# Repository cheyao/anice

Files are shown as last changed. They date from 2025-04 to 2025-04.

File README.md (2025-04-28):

# Icedev & Anice

*"FPGAs work like this. You don't tell them what to do, you tell them what to BE."*

An FPGA is a chip that can be configured on the hardware level. You can basically make your own CPU and GPU on it.

This project is composed of a PCB duo, that will be later joined together:

The first PCB called "icedev" is a ICE40 FPGA development board:
- 16MHz clock
- 64KiB eeprom
- 128MiB flash
- 1.2MiB of RAM
- dual usb-c
- multi voltage
It's equivalent is like the raspberry pico (orph pico)

The second, called "anice":
- 256MiB of ram
- 128MiB of flash
- HDMI port
- triple USB C with JTAG converter
- SDCard Reader
- dual 25MHz clock and 200MHz built-in clock
- multiple indicator lights
- only 4 layer PCB

View online demo on [kicanvas](https://kicanvas.org/?github=https%3A%2F%2Fgithub.com%2Fcheyao%2Fanice%2Ftree%2Fmain%2Fsrc%2F)!

The repo stucture is a bit messy because I wanted the two designs to appear together on kicanvas.

## Anice:



## Icedev:



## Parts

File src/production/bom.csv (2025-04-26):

Designator | Footprint | Quantity | Value | LCSC Part #
C10, C21, C27, C29 | 0603 | 4 | 100pF | C14858
C11, C12, C2, C25, C28, C3, C30, C32, C4, C8, C9 | 0603 | 11 | 10uF | C19702
C13, C14, C15, C16, C17, C18, C19, C20 | 0402 | 8 | 22nF | C1532
C22 | 0603 | 1 | 22uF | C59461
C23, C26, C31, C33, C34, C35, C36, C37, C38, C39, C41, C42, C43 | 0402 | 13 | 100nF | C1525
C40 | 0402 | 1 | 5pF | C541339
D1 | 0603 | 1 | RED | C2286
D2 | 0603 | 1 | GREEN | C2994781
D3 | 0603 | 1 | YELLOW | C72038
J2 | SDCard molex | 1 | Micro_SD_Card_Det1 | C20613194
J3, J4, J5 | USB_C_Receptacle_GCT_USB4105-xx-A_16P_TopMnt_Horizontal | 3 | USB_C_Receptacle_USB2.0_14P | C2765186
J7 | XKB Connection A71-05H4-111N1 | 1 | HDMI_C_1.3 | C2682170
L1, L2, L3 | 1008 | 3 | 2.2uH | C285758
R1, R2, R3, R4, R6, R7 | 0603 | 6 | 5.1k | C23186
R10, R8 | 0603 | 2 | 470 | C23179
R11 | 0603 | 1 | 100k | C25803
R12, R13, R16, R17, R23, R24, RB2 | 0603 | 7 | 4.7k | C23162
R14, R15, RB3 | 0603 | 3 | 3.3k | C22978
R18 | 0603 | 1 | 1k | C21190
R19, R20, R21, R22, R9 | 0603 | 5 | 10k | C25804
R25, R26, R5 | 0603 | 3 | 549 | C23204
R38 | 0603 | 1 | 0.47 | C3013349
RA1, RA2, RA3 | 0603 | 3 | 15k | C22809
RB1 | 0603 | 1 | 18k | C25810
U1 | BGA-256_14.0x14.0mm_Layout16x16_P0.8mm_Ball0.45mm_Pad0.32mm_NSMD | 1 | ECP5U_12_CABGA256 | C1521614
U10 | TSOP-II-54_22.2x10.16mm_P0.8mm | 1 | W9825G6KH-6 | C62246
U11 | SOIC-8_5.3x5.3mm_P1.27mm | 1 | W25Q128JVS | C97521
U12, U13, U14 | SOT-563 | 3 | TLV62569DRL | C163217
U5, U6, U8 | Texas_DRT-3 | 3 | TPD2EUSB30 | C2844720
U7 | QFN-20-1EP_4x4mm_P0.5mm_EP2.5x2.5mm | 1 | FT231XQ | C132159
U9 | VSSOP-8_2.3x2mm_P0.5mm | 1 | PCA9306DC1 | C129510
Y1 | Crystal_SMD_3225-4Pin_3.2x2.5mm | 1 | ECS-2520MV-xxx-xx | C5189451

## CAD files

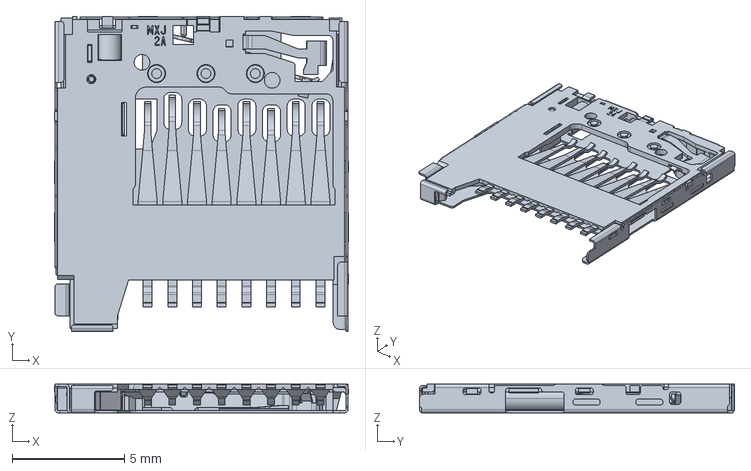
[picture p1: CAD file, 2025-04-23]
src/5033981892.stp
13.1 x 14.0 x 1.28 mm

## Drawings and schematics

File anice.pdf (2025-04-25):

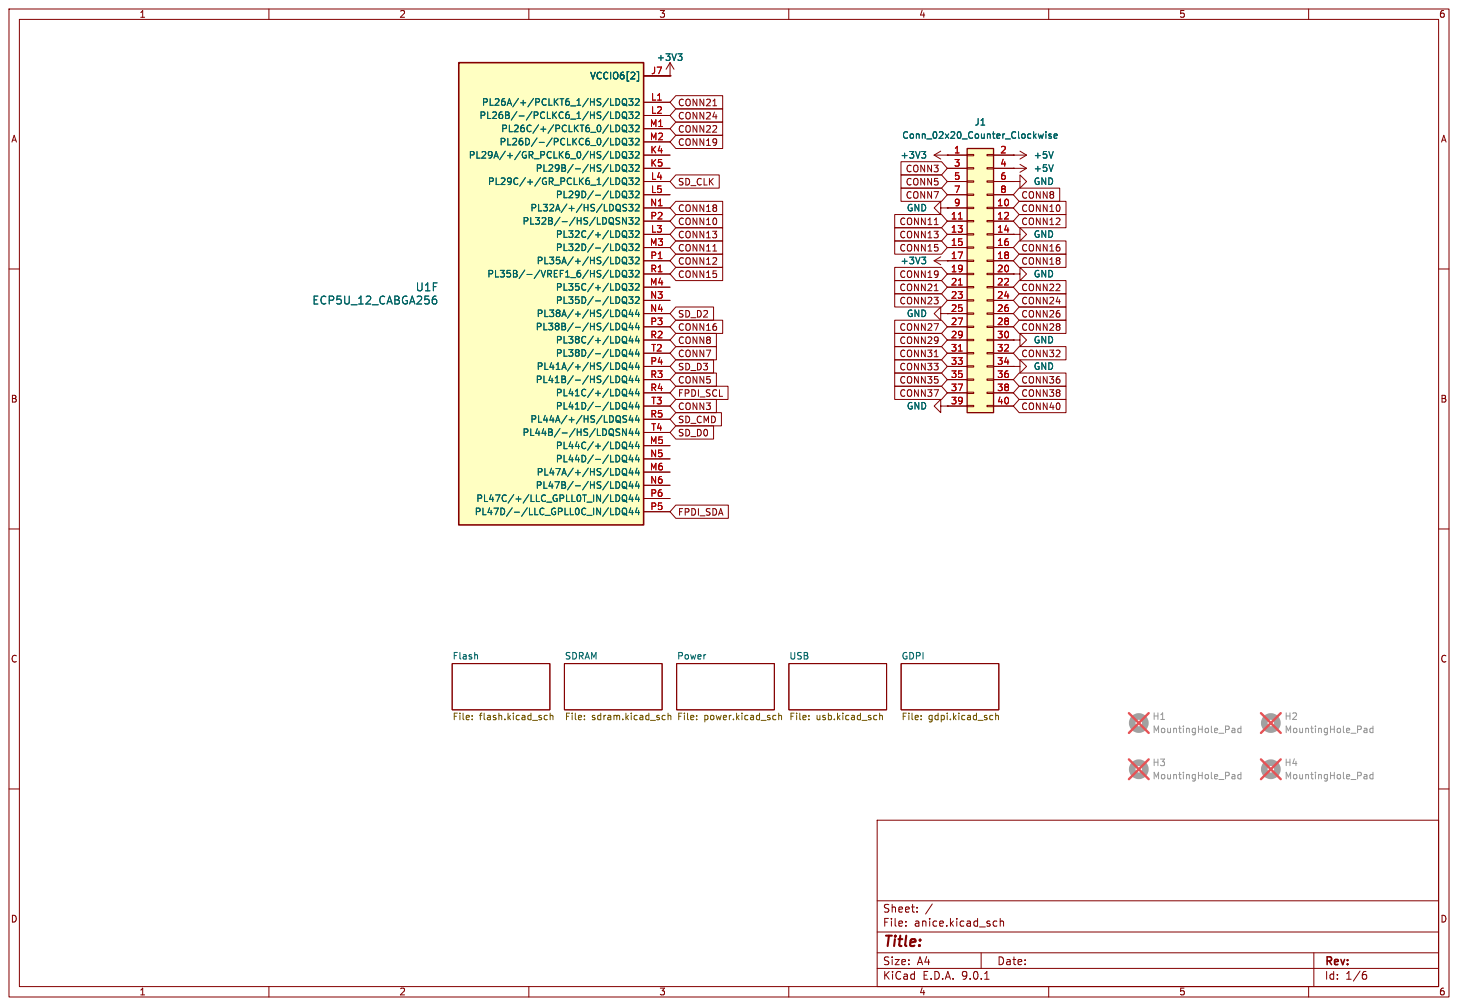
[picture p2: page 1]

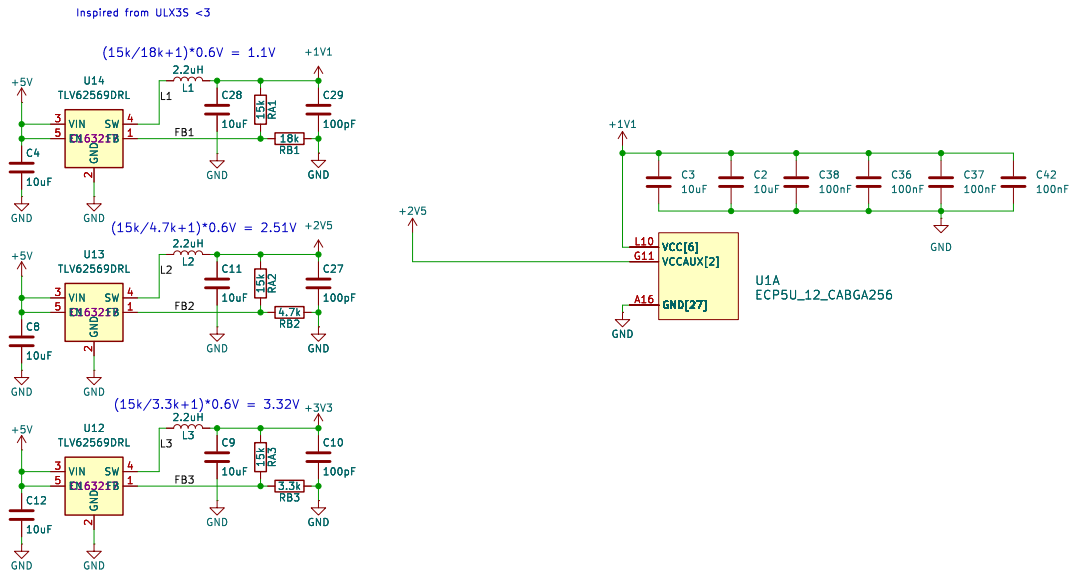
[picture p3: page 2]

2 SW 4 FB 1 U13 TLV62569DRL C163217 +5V
Id: 2/6 Title: File: power.kicad_sch Sheet: /Power/ +3V3 +5V

2 SW 4 FB 1 U13 TLV62569DRL C163217 VIN 3 EN 5 GND

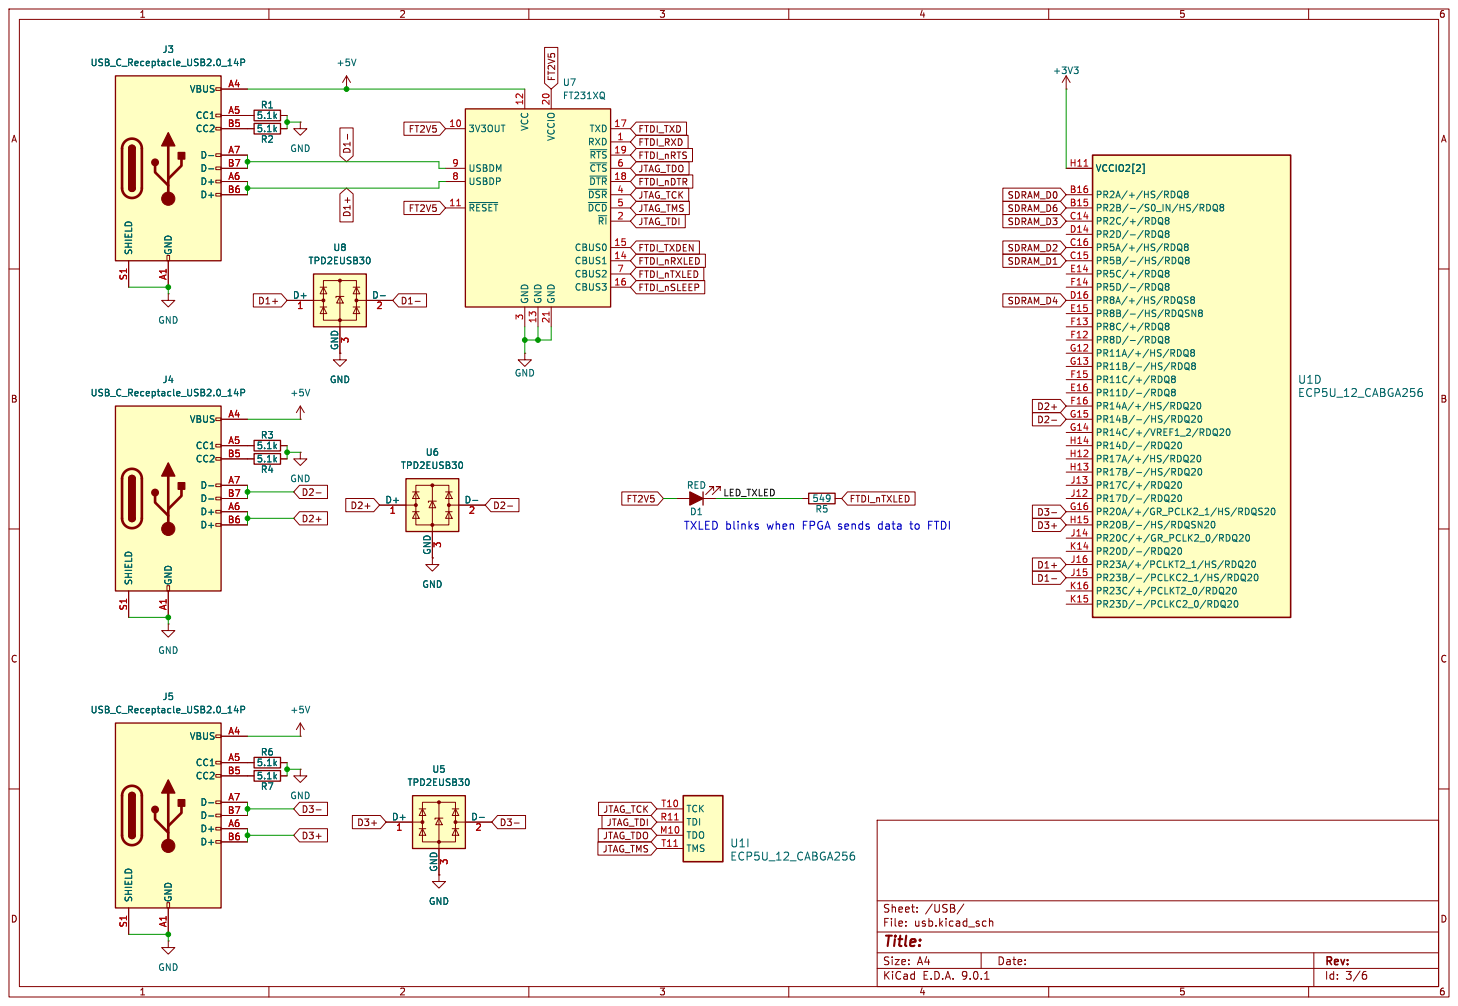
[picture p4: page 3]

3 GND 13 VCCIO 20 GND 21 TXD 17 RXD 1 ~{RTS}19 ~{CTS}6 ~{DTR}18 ~{DSR}4 ~{DCD}5 ~{RI}2 CBUS0 15 CBUS1 14 CBUS2 7 CBUS3 16 U7 FT231XQ
JTAG_TDI FTDI_RXD

Id: 3/6 Title: File: usb.kicad_sch Sheet: /USB/

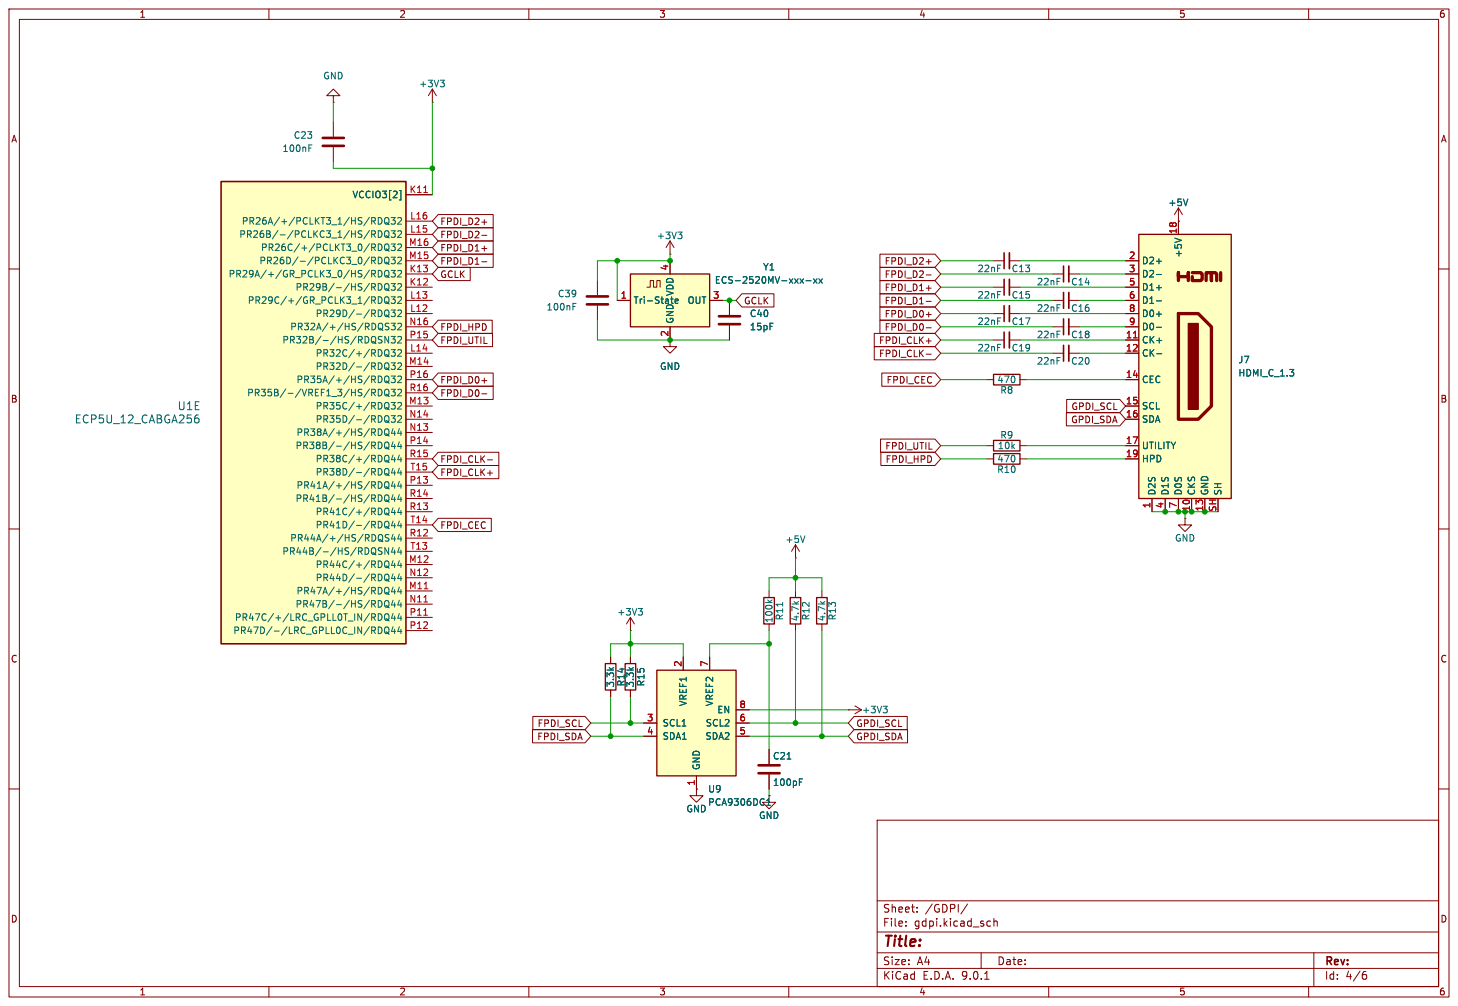
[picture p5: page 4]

2 OUT 3 Y1 ECS-2520MV-xxx-xx +3V3 3.3k R14 3.3k R15 SCL1 3 SDA1 4 VREF1

7 EN 8 SCL2 6 SDA2 5 3.3k R14 3.3k R15 Y1 ECS-2520MV-xxx-xx Tri-State 1 VDD

7 CKS 10 GND 13 SH SH

Id: 4/6 Title: File: gdpi.kicad_sch Sheet: /GDPI/

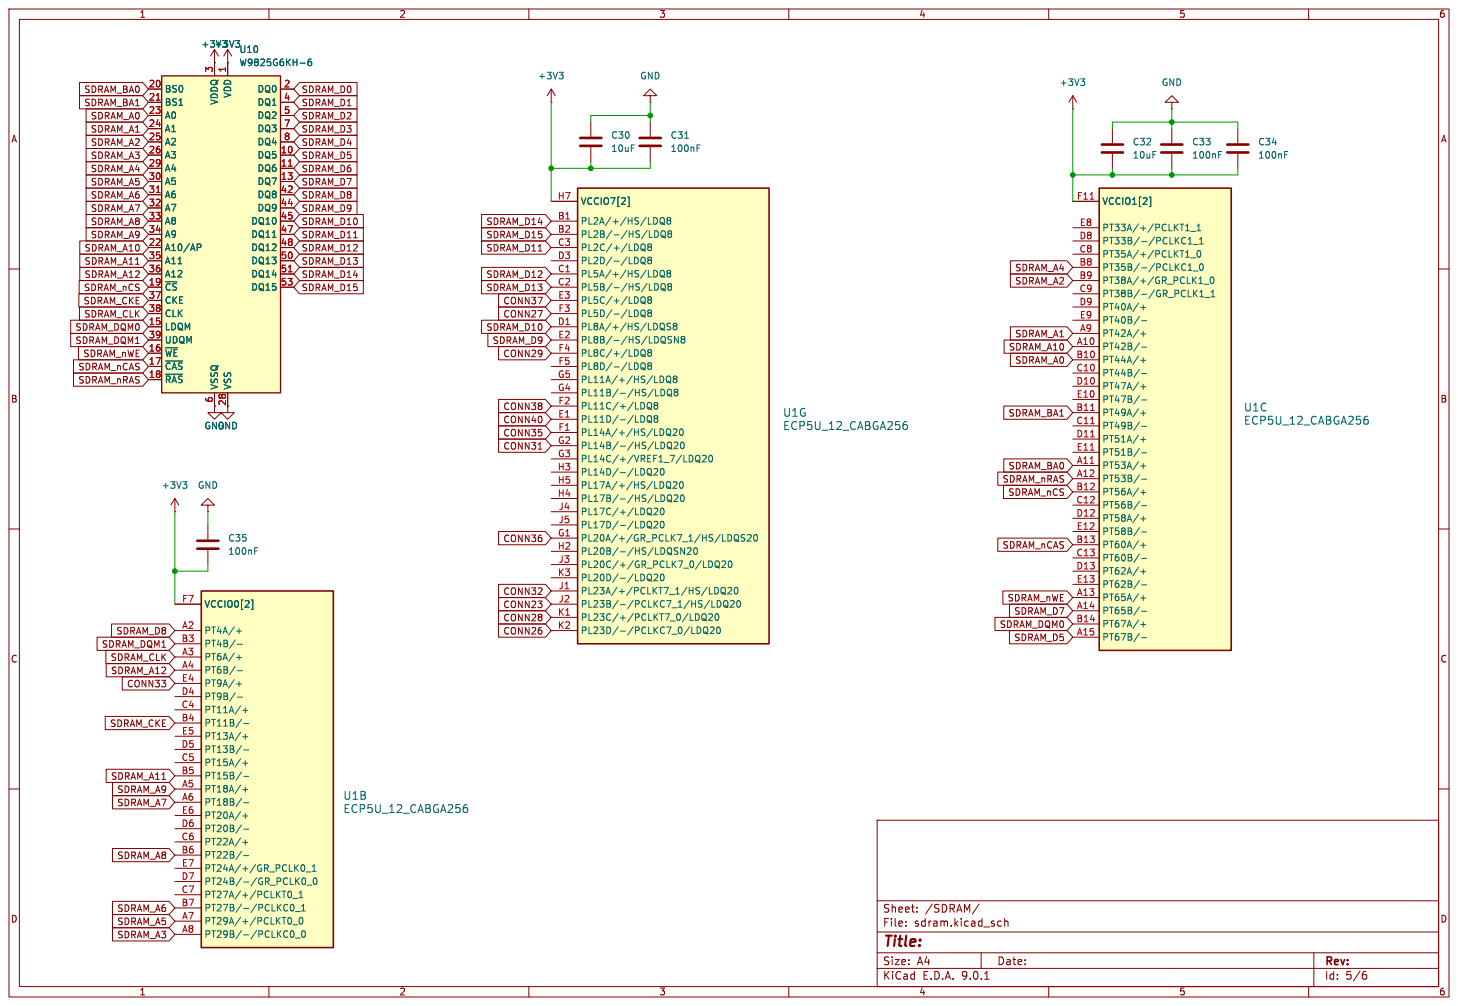
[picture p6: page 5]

U10 W9825G6KH-6 BS0 20 BS1 21 A0 23 A1 24 A2 25 A3 26 A4 29 A5 30 A6 31 A7 32 A8 33 A9 34 A10/AP 22 A11 35 A12 36 ~{CS} 19 CKE 37 CLK 38

1 VSS 28 DQ0 2 DQ1 4 DQ2 5 DQ3 7 DQ4 8 DQ5 10 DQ6 11 DQ7 13 DQ8 42 DQ9 44 DQ10 45 DQ11 47 DQ12 48 DQ13 50 DQ14 51 DQ15 53 U10 W9825G6KH-6 GND GND GND GND

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

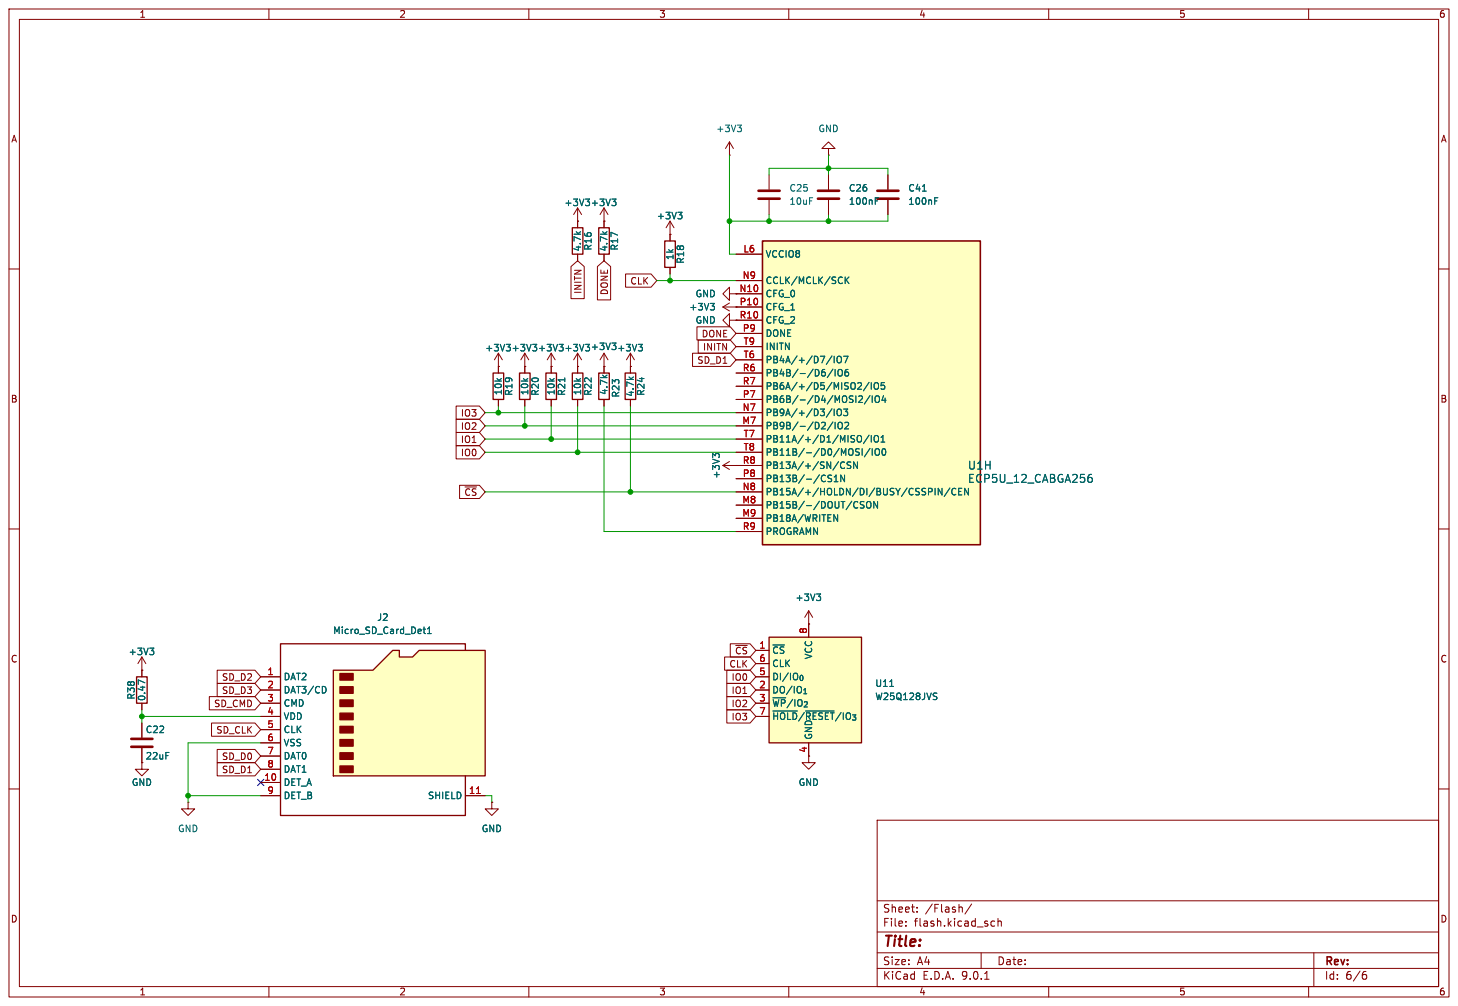
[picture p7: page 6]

Id: 6/6 Title: File: flash.kicad_sch Sheet: /Flash/

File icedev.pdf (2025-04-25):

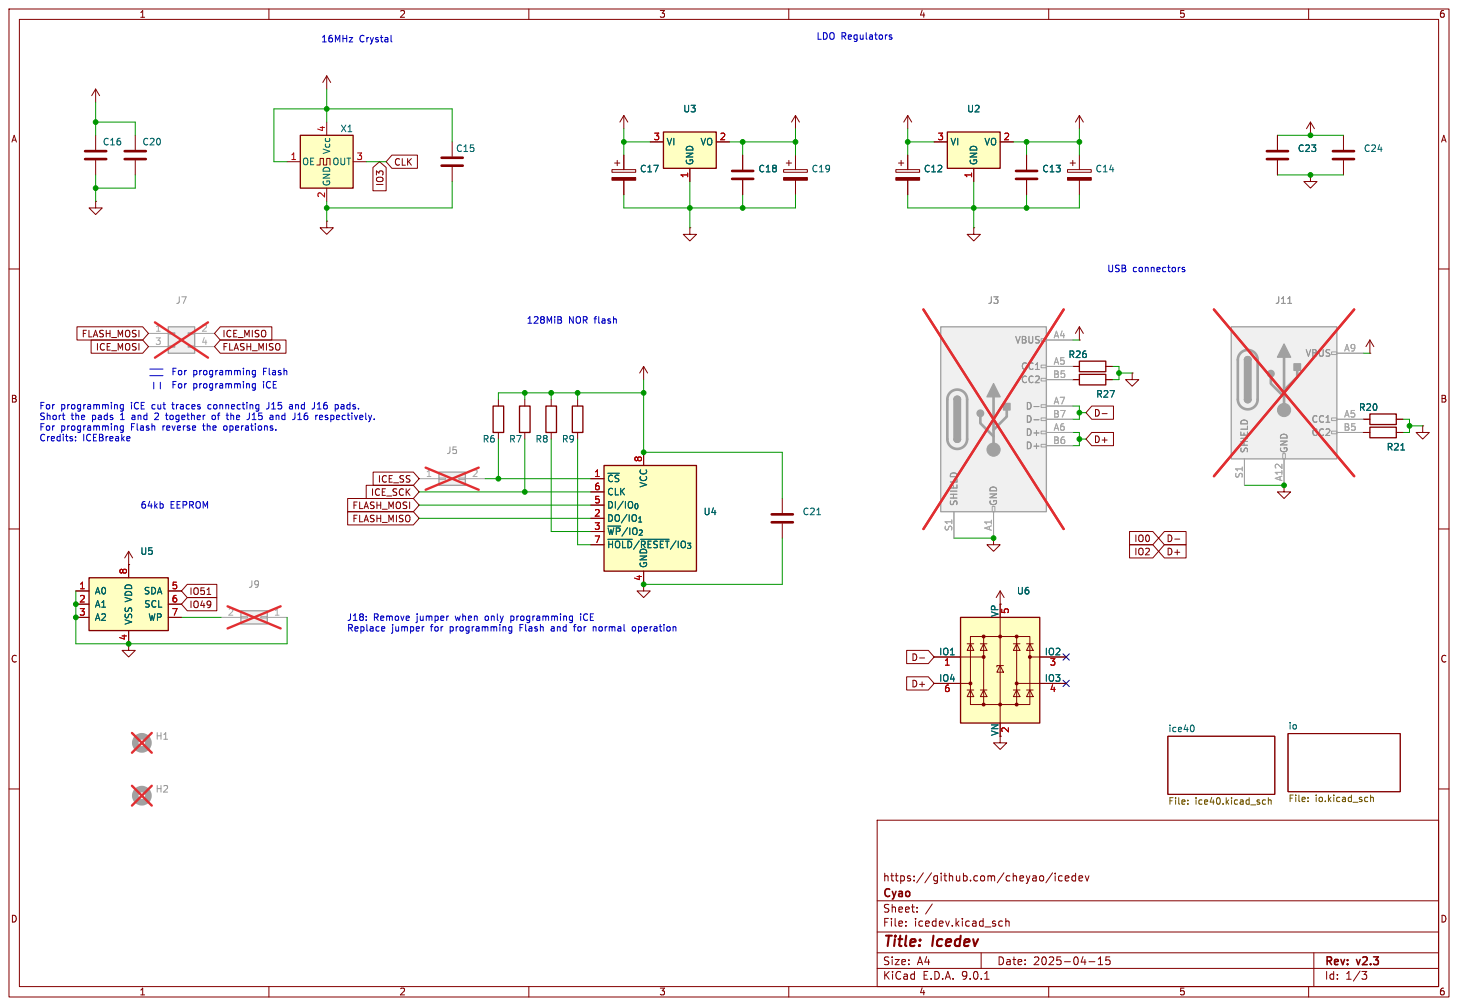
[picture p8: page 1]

1 VO 2 U2 OE 1 Vcc 4 GND

https://github.com/cheyao/icedev
File: icedev.kicad_sch Sheet: / Cyao

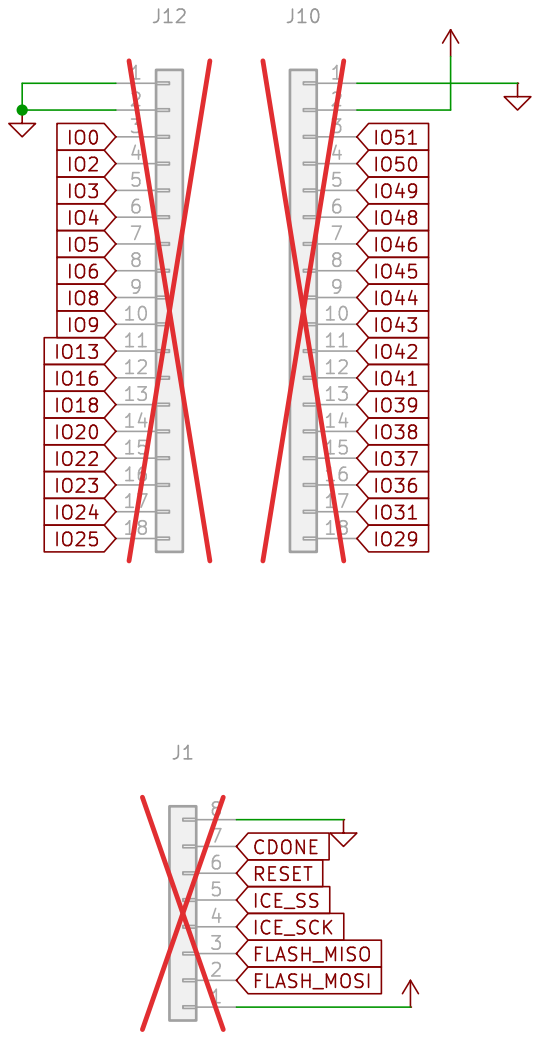
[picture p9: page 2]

Id: 2/3 Title: File: io.kicad_sch Sheet: /io/ 12345678

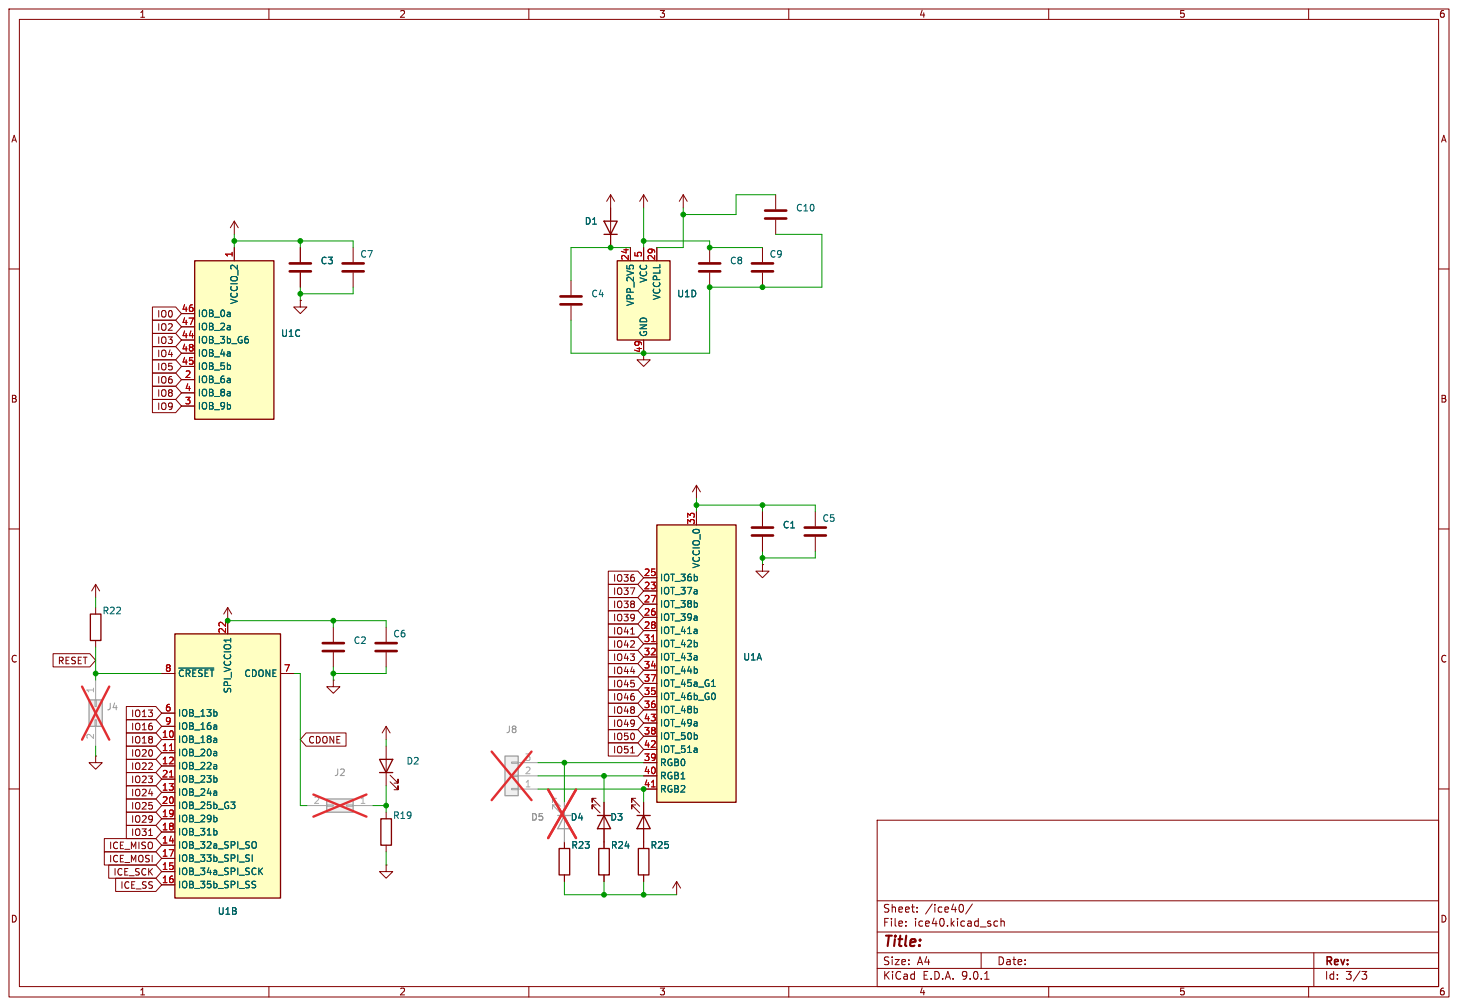
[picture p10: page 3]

Id: 3/3 Title: File: ice40.kicad_sch Sheet: /ice40/

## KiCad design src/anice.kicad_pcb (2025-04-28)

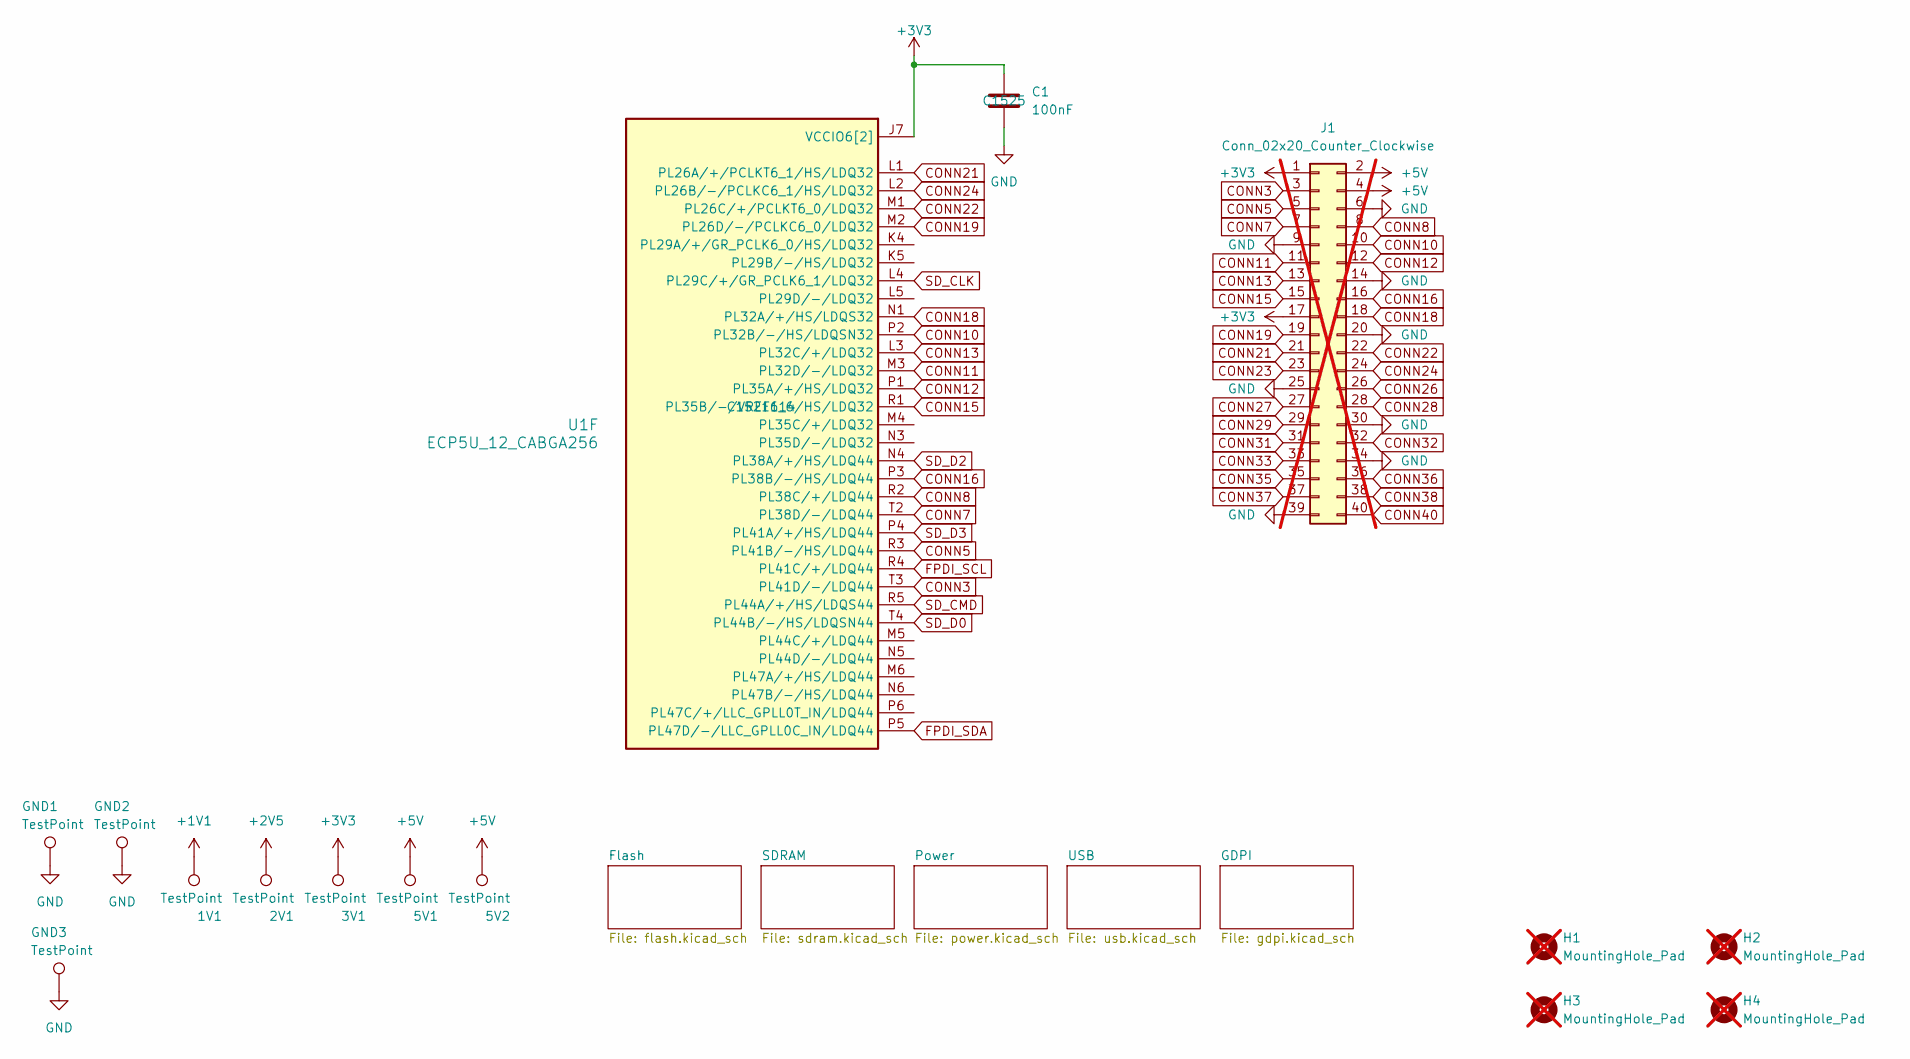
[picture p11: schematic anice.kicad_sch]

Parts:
1V1, 2V1, 3V1, 5V1, 5V2: TestPoint; TestPoint_Pad_D1.5mm
C1: 100nF; C_0402_1005Metric; JLCPCB Part # C1525
GND1, GND2, GND3: TestPoint; TestPoint_Pad_D1.5mm
H1, H2, H3, H4: MountingHole_Pad; MountingHole_2.5mm; not fitted
J1: Conn_02x20_Counter_Clockwise; PinHeader_2x20_P2.54mm_Vertical; not fitted
U1: ECP5U_12_CABGA256; BGA-256_14.0x14.0mm_Layout16x16_P0.8mm_Ball0.45mm_Pad0.32mm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; JLCPCB Part # C1521614

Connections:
+1V1: 1V1.1; also elsewhere on the board
+2V5: 2V1.1; also elsewhere on the board
+3V3: 3V1.1, C1.1, J1.1, J1.17, U1.J6 (VCCIO6[2]), U1.J7 (VCCIO6[2]); also elsewhere on the board
+5V: 5V1.1, 5V2.1, J1.2, J1.4; also elsewhere on the board
CONN3: J1.3, U1.T3 (PL41D/-/LDQ44)
CONN5: J1.5, U1.R3 (PL41B/-/HS/LDQ44)
CONN7: J1.7, U1.T2 (PL38D/-/LDQ44)
CONN8: J1.8, U1.R2 (PL38C/+/LDQ44)
CONN10: J1.10, U1.P2 (PL32B/-/HS/LDQSN32)
CONN11: J1.11, U1.M3 (PL32D/-/LDQ32)
CONN12: J1.12, U1.P1 (PL35A/+/HS/LDQ32)
CONN13: J1.13, U1.L3 (PL32C/+/LDQ32)
CONN15: J1.15, U1.R1 (PL35B/-/VREF1_6/HS/LDQ32)
CONN16: J1.16, U1.P3 (PL38B/-/HS/LDQ44)
CONN18: J1.18, U1.N1 (PL32A/+/HS/LDQS32)
CONN19: J1.19, U1.M2 (PL26D/-/PCLKC6_0/LDQ32)
CONN21: J1.21, U1.L1 (PL26A/+/PCLKT6_1/HS/LDQ32)
CONN22: J1.22, U1.M1 (PL26C/+/PCLKT6_0/LDQ32)
CONN23: J1.23; also elsewhere on the board
CONN24: J1.24, U1.L2 (PL26B/-/PCLKC6_1/HS/LDQ32)
CONN26: J1.26; also elsewhere on the board
CONN27: J1.27; also elsewhere on the board
CONN28: J1.28; also elsewhere on the board
CONN29: J1.29; also elsewhere on the board
CONN31: J1.31; also elsewhere on the board
CONN32: J1.32; also elsewhere on the board
CONN33: J1.33; also elsewhere on the board
CONN35: J1.35; also elsewhere on the board
CONN36: J1.36; also elsewhere on the board
CONN37: J1.37; also elsewhere on the board
CONN38: J1.38; also elsewhere on the board
CONN40: J1.40; also elsewhere on the board
FPDI_SCL: U1.R4 (PL41C/+/LDQ44); also elsewhere on the board
FPDI_SDA: U1.P5 (PL47D/-/LLC_GPLL0C_IN/LDQ44); also elsewhere on the board
GND: C1.2, GND1.1, GND2.1, GND3.1, J1.6, J1.9, J1.14, J1.20, J1.25, J1.30, J1.34, J1.39; also elsewhere on the board
SD_CLK: U1.L4 (PL29C/+/GR_PCLK6_1/LDQ32); also elsewhere on the board
SD_CMD: U1.R5 (PL44A/+/HS/LDQS44); also elsewhere on the board
SD_D0: U1.T4 (PL44B/-/HS/LDQSN44); also elsewhere on the board
SD_D2: U1.N4 (PL38A/+/HS/LDQ44); also elsewhere on the board
SD_D3: U1.P4 (PL41A/+/HS/LDQ44); also elsewhere on the board

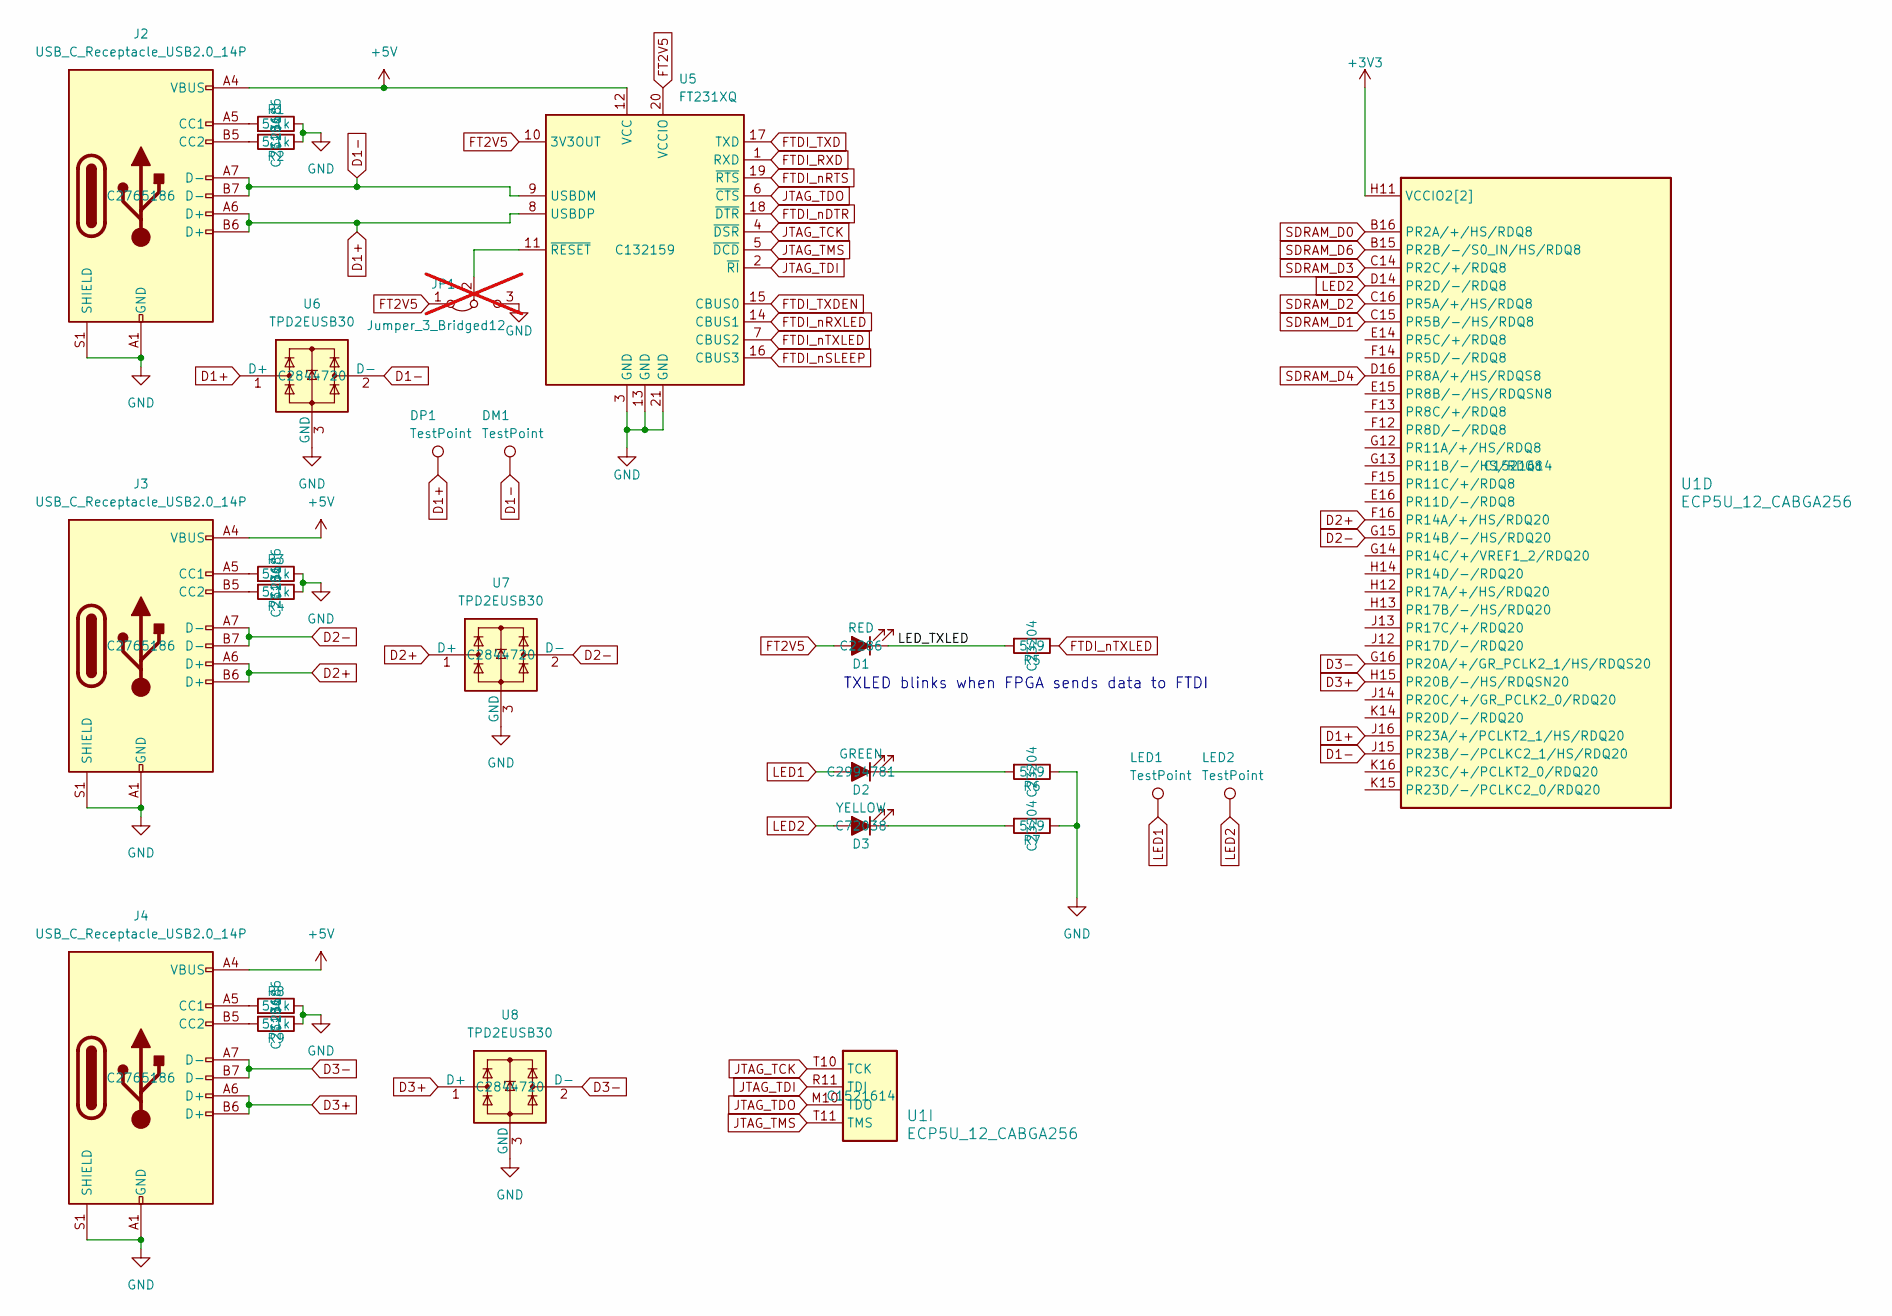
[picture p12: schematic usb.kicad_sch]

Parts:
D1: RED; LED_0603_1608Metric; JLCPCB Part # C2286
D2: GREEN; LED_0603_1608Metric; JLCPCB Part # C2994781
D3: YELLOW; LED_0603_1608Metric; JLCPCB Part # C72038
DM1: TestPoint; TestPoint_Pad_D1.5mm
DP1: TestPoint; TestPoint_Pad_D1.5mm
J2, J3, J4: USB_C_Receptacle_USB2.0_14P; USB_C_Receptacle_GCT_USB4105-xx-A_16P_TopMnt_Horizontal; JLCPCB Part # C2765186
JP1: Jumper_3_Bridged12; SolderJumper-3_P1.3mm_Bridged2Bar12_RoundedPad1.0x1.5mm; not fitted
LED1, LED2: TestPoint; TestPoint_Pad_D1.5mm
R1, R2, R3, R4, R8, R9: 5.1k; R_0603_1608Metric; JLCPCB Part # C23186
R5, R6, R7: 549; R_0603_1608Metric; JLCPCB Part # C23204
U1: ECP5U_12_CABGA256; BGA-256_14.0x14.0mm_Layout16x16_P0.8mm_Ball0.45mm_Pad0.32mm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; JLCPCB Part # C1521614
U5: FT231XQ; QFN-20-1EP_4x4mm_P0.5mm_EP2.5x2.5mm; JLCPCB Part # C132159
U6, U7, U8: TPD2EUSB30; Texas_DRT-3; JLCPCB Part # C2844720

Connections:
+3V3: U1.H11 (VCCIO2[2]), U1.J11 (VCCIO2[2]); also elsewhere on the board
+5V: J2.A4 (VBUS), J2.A9 (VBUS), J2.B4 (VBUS), J2.B9 (VBUS), J3.A4 (VBUS), J3.A9 (VBUS), J3.B4 (VBUS), J3.B9 (VBUS), J4.A4 (VBUS), J4.A9 (VBUS), J4.B4 (VBUS), J4.B9 (VBUS), U5.12 (VCC); also elsewhere on the board
/USB/LED_TXLED: D1.1 (K), R5.2
D1+: DP1.1, J2.A6 (D+), J2.B6 (D+), U1.J16 (PR23A/+/PCLKT2_1/HS/RDQ20), U5.8 (USBDP), U6.1 (D+)
D1-: DM1.1, J2.A7 (D-), J2.B7 (D-), U1.J15 (PR23B/-/PCLKC2_1/HS/RDQ20), U5.9 (USBDM), U6.2 (D-)
D2+: J3.A6 (D+), J3.B6 (D+), U1.F16 (PR14A/+/HS/RDQ20), U7.1 (D+)
D2-: J3.A7 (D-), J3.B7 (D-), U1.G15 (PR14B/-/HS/RDQ20), U7.2 (D-)
D3+: J4.A6 (D+), J4.B6 (D+), U1.H15 (PR20B/-/HS/RDQSN20), U8.1 (D+)
D3-: J4.A7 (D-), J4.B7 (D-), U1.G16 (PR20A/+/GR_PCLK2_1/HS/RDQS20), U8.2 (D-)
FT2V5: D1.2 (A), JP1.1 (A), U5.10 (3V3OUT), U5.20 (VCCIO)
FTDI_RXD: U5.1 (RXD)
FTDI_TXD: U5.17 (TXD)
FTDI_TXDEN: U5.15 (CBUS0)
FTDI_nDTR: U5.18 (~DTR)
FTDI_nRTS: U5.19 (~RTS)
FTDI_nRXLED: U5.14 (CBUS1)
FTDI_nSLEEP: U5.16 (CBUS3)
FTDI_nTXLED: R5.1, U5.7 (CBUS2)
GND: J2.A1 (GND), J2.A12 (GND), J2.B1 (GND), J2.B12 (GND), J2.S1 (SHIELD), J3.A1 (GND), J3.A12 (GND), J3.B1 (GND), J3.B12 (GND), J3.S1 (SHIELD), J4.A1 (GND), J4.A12 (GND), J4.B1 (GND), J4.B12 (GND), J4.S1 (SHIELD), JP1.3 (B), R1.1, R2.1, R3.1, R4.1, R6.1, R7.1, R8.1, R9.1, U5.3 (GND), U5.13 (GND), U5.21 (GND), U6.3 (GND), U7.3 (GND), U8.3 (GND); also elsewhere on the board
JTAG_TCK: U1.T10 (TCK), U5.4 (~DSR)
JTAG_TDI: U1.R11 (TDI), U5.2 (~RI)
JTAG_TDO: U1.M10 (TDO), U5.6 (~CTS)
JTAG_TMS: U1.T11 (TMS), U5.5 (~DCD)
LED1: D2.2 (A), LED1.1; also elsewhere on the board
LED2: D3.2 (A), LED2.1, U1.D14 (PR2D/-/RDQ8)
unnamed: D2.1 (K), R6.2
unnamed: D3.1 (K), R7.2
unnamed: J2.A5 (CC1), R1.2
unnamed: J2.B5 (CC2), R2.2
unnamed: J3.A5 (CC1), R3.2
unnamed: J3.B5 (CC2), R4.2
unnamed: J4.A5 (CC1), R8.2
unnamed: J4.B5 (CC2), R9.2
unnamed: JP1.2 (C), U5.11 (~RESET)
SDRAM_D0: U1.B16 (PR2A/+/HS/RDQ8); also elsewhere on the board
SDRAM_D1: U1.C15 (PR5B/-/HS/RDQ8); also elsewhere on the board
SDRAM_D2: U1.C16 (PR5A/+/HS/RDQ8); also elsewhere on the board
SDRAM_D3: U1.C14 (PR2C/+/RDQ8); also elsewhere on the board
SDRAM_D4: U1.D16 (PR8A/+/HS/RDQS8); also elsewhere on the board
SDRAM_D6: U1.B15 (PR2B/-/S0_IN/HS/RDQ8); also elsewhere on the board

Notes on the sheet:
TXLED blinks when FPGA sends data to FTDI

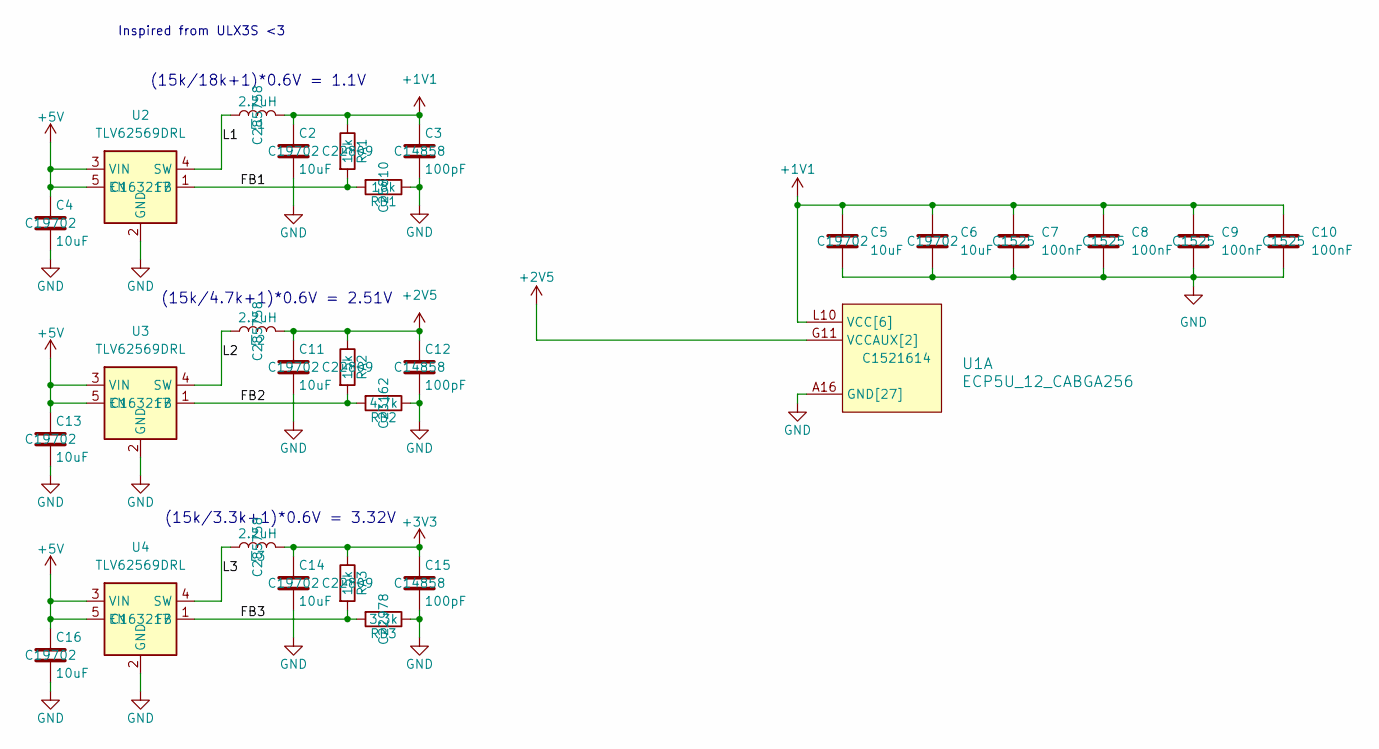
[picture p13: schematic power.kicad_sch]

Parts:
C2, C4, C5, C6, C11, C13, C14, C16: 10uF; C_0603_1608Metric; JLCPCB Part # C19702
C3, C12, C15: 100pF; C_0603_1608Metric; JLCPCB Part # C14858
C7, C8, C9, C10: 100nF; C_0402_1005Metric; JLCPCB Part # C1525
L1, L2, L3: 2.2uH; L_1008_2520Metric; JLCPCB Part # C285758
RA1, RA2, RA3: 15k; R_0603_1608Metric; JLCPCB Part # C22809
RB1: 18k; R_0603_1608Metric; JLCPCB Part # C25810
RB2: 4.7k; R_0603_1608Metric; JLCPCB Part # C23162
RB3: 3.3k; R_0603_1608Metric; JLCPCB Part # C22978
U1: ECP5U_12_CABGA256; BGA-256_14.0x14.0mm_Layout16x16_P0.8mm_Ball0.45mm_Pad0.32mm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; JLCPCB Part # C1521614
U2, U3, U4: TLV62569DRL; SOT-563; JLCPCB Part # C163217

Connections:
+1V1: C2.1, C3.1, C5.1, C6.1, C7.1, C8.1, C9.1, C10.1, L1.2, RA1.1, U1.G6 (VCC[6]), U1.G7 (VCC[6]), U1.G9 (VCC[6]), U1.L8 (VCC[6]), U1.L9 (VCC[6]), U1.L10 (VCC[6]); also elsewhere on the board
+2V5: C11.1, C12.1, L2.2, RA2.1, U1.G11 (VCCAUX[2]), U1.L7 (VCCAUX[2]); also elsewhere on the board
+3V3: C14.1, C15.1, L3.2, RA3.1; also elsewhere on the board
+5V: C4.1, C13.1, C16.1, U2.3 (VIN), U2.5 (EN), U3.3 (VIN), U3.5 (EN), U4.3 (VIN), U4.5 (EN); also elsewhere on the board
/Power/FB1: RA1.2, RB1.2, U2.1 (FB)
/Power/FB2: RA2.2, RB2.2, U3.1 (FB)
/Power/FB3: RA3.2, RB3.2, U4.1 (FB)
/Power/L1: L1.1, U2.4 (SW)
/Power/L2: L2.1, U3.4 (SW)
/Power/L3: L3.1, U4.4 (SW)
GND: C2.2, C3.2, C4.2, C5.2, C6.2, C7.2, C8.2, C9.2, C10.2, C11.2, C12.2, C13.2, C14.2, C15.2, C16.2, RB1.1, RB2.1, RB3.1, U1.A1 (GND[27]), U1.A16 (GND[27]), U1.D2 (GND[27]), U1.D15 (GND[27]), U1.F8 (GND[27]), U1.F9 (GND[27]), U1.G8 (GND[27]), U1.G10 (GND[27]), U1.H1 (GND[27]), U1.H8 (GND[27]), U1.H9 (GND[27]), U1.H10 (GND[27]), U1.H16 (GND[27]), U1.J8 (GND[27]), U1.J9 (GND[27]), U1.J10 (GND[27]), U1.K6 (GND[27]), U1.K7 (GND[27]), U1.K8 (GND[27]), U1.K9 (GND[27]), U1.K10 (GND[27]), U1.N2 (GND[27]), U1.N15 (GND[27]), U1.T1 (GND[27]), U1.T5 (GND[27]), U1.T12 (GND[27]), U1.T16 (GND[27]), U2.2 (GND), U3.2 (GND), U4.2 (GND); also elsewhere on the board

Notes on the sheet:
(15k/18k+1)*0.6V = 1.1V
(15k/4.7k+1)*0.6V = 2.51V
(15k/3.3k+1)*0.6V = 3.32V
Inspired from ULX3S <3

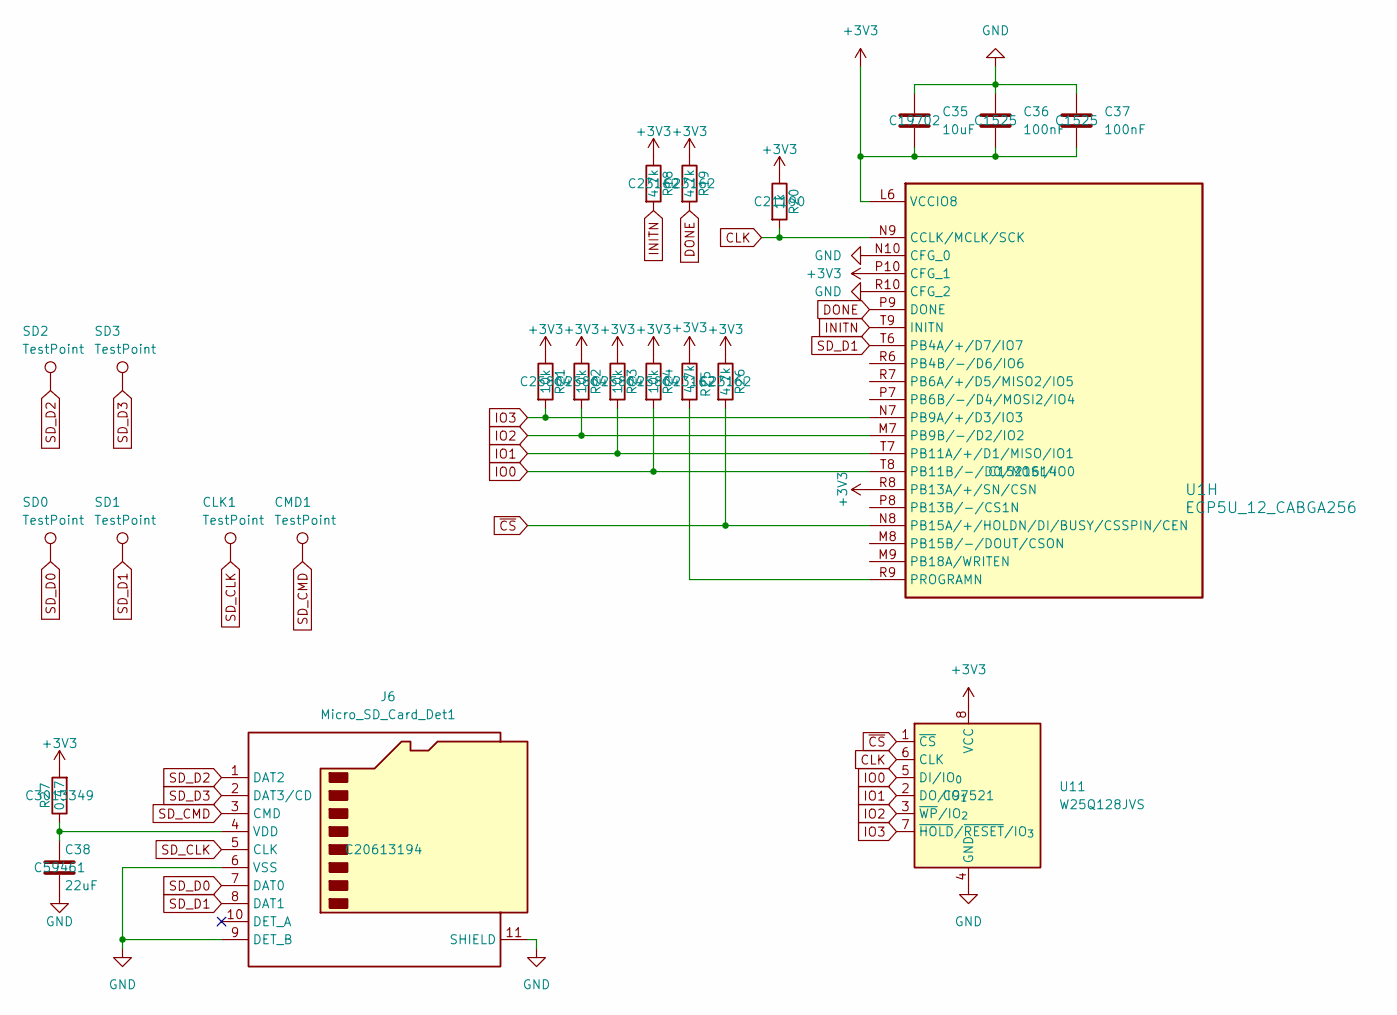
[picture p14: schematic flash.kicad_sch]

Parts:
C35: 10uF; C_0603_1608Metric; JLCPCB Part # C19702
C36, C37: 100nF; C_0402_1005Metric; JLCPCB Part # C1525
C38: 22uF; C_0603_1608Metric; JLCPCB Part # C59461
CLK1: TestPoint; TestPoint_Pad_D1.5mm
CMD1: TestPoint; TestPoint_Pad_D1.5mm
J6: Micro_SD_Card_Det1; SDCard molex; JLCPCB Part # C20613194
R18, R19, R25, R26: 4.7k; R_0603_1608Metric; JLCPCB Part # C23162
R20: 1k; R_0603_1608Metric; JLCPCB Part # C21190
R21, R22, R23, R24: 10k; R_0603_1608Metric; JLCPCB Part # C25804
R27: 0.47; R_0603_1608Metric; JLCPCB Part # C3013349
SD0, SD1, SD2, SD3: TestPoint; TestPoint_Pad_D1.5mm
U1: ECP5U_12_CABGA256; BGA-256_14.0x14.0mm_Layout16x16_P0.8mm_Ball0.45mm_Pad0.32mm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; JLCPCB Part # C1521614
U11: W25Q128JVS; SOIC-8_5.3x5.3mm_P1.27mm; JLCPCB Part # C97521

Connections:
+3V3: C35.2, C36.2, C37.2, R18.1, R19.1, R20.1, R21.1, R22.1, R23.1, R24.1, R25.1, R26.1, R27.2, U1.L6 (VCCIO8), U1.P10 (CFG_1), U1.R8 (PB13A/+/SN/CSN), U11.8 (VCC); also elsewhere on the board
CLK: R20.2, U1.N9 (CCLK/MCLK/SCK), U11.6 (CLK)
DONE: R19.2, U1.P9 (DONE)
GND: C35.1, C36.1, C37.1, C38.2, J6.6 (VSS), J6.9 (DET_B), J6.11 (SHIELD), U1.N10 (CFG_0), U1.R10 (CFG_2), U11.4 (GND); also elsewhere on the board
INITN: R18.2, U1.T9 (INITN)
IO0: R24.2, U1.T8 (PB11B/-/D0/MOSI/IO0), U11.5 (DI/IO_{0})
IO1: R23.2, U1.T7 (PB11A/+/D1/MISO/IO1), U11.2 (DO/IO_{1})
IO2: R22.2, U1.M7 (PB9B/-/D2/IO2), U11.3 (~WP/IO_{2})
IO3: R21.2, U1.N7 (PB9A/+/D3/IO3), U11.7 (~HOLD/~RESET/IO_{3})
unnamed: C38.1, J6.4 (VDD), R27.1
unnamed: R25.2, U1.R9 (PROGRAMN)
SD_CLK: CLK1.1, J6.5 (CLK); also elsewhere on the board
SD_CMD: CMD1.1, J6.3 (CMD); also elsewhere on the board
SD_D0: J6.7 (DAT0), SD0.1; also elsewhere on the board
SD_D1: J6.8 (DAT1), SD1.1, U1.T6 (PB4A/+/D7/IO7)
SD_D2: J6.1 (DAT2), SD2.1; also elsewhere on the board
SD_D3: J6.2 (DAT3/CD), SD3.1; also elsewhere on the board
~CS: R26.2, U1.N8 (PB15A/+/HOLDN/DI/BUSY/CSSPIN/CEN), U11.1 (~CS)

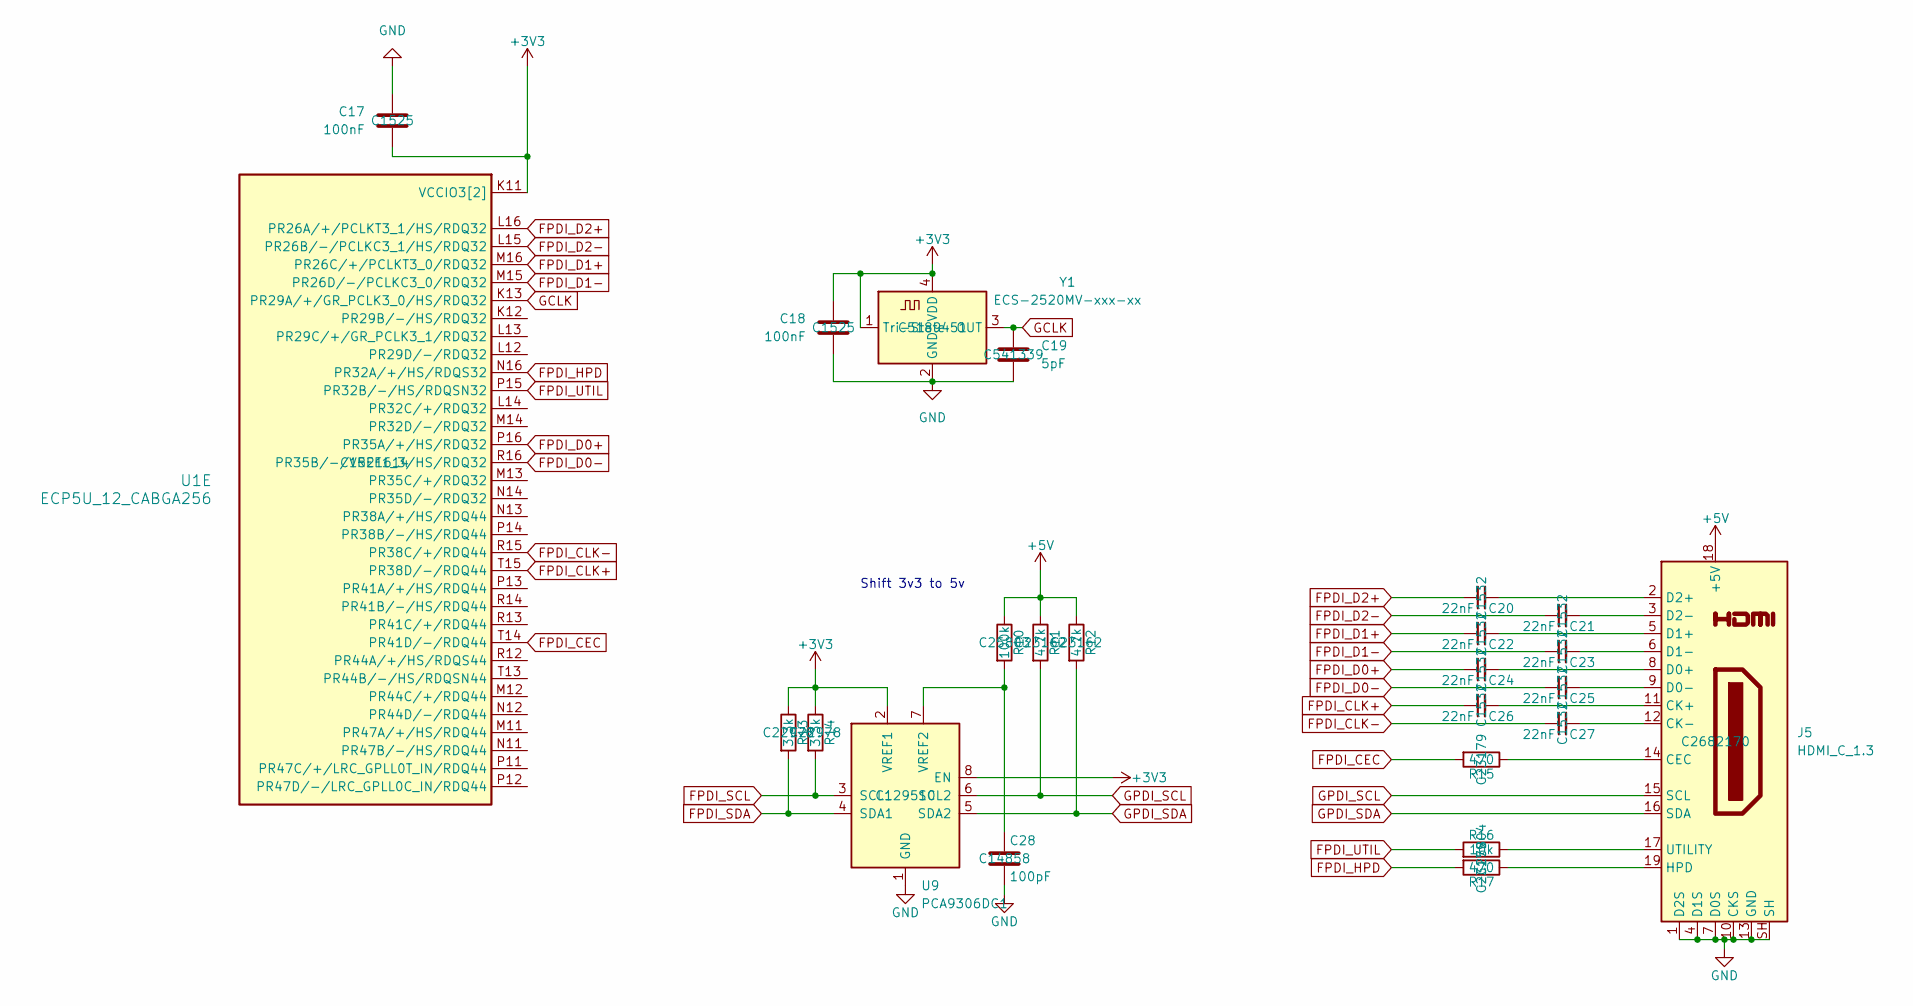
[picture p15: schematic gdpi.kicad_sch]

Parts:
C17, C18: 100nF; C_0402_1005Metric; JLCPCB Part # C1525
C19: 5pF; C_0402_1005Metric; JLCPCB Part # C541339
C20, C21, C22, C23, C24, C25, C26, C27: 22nF; C_0402_1005Metric; JLCPCB Part # C1532
C28: 100pF; C_0603_1608Metric; JLCPCB Part # C14858
J5: HDMI_C_1.3; XKB Connection A71-05H4-111N1; JLCPCB Part # C2682170
R10: 100k; R_0603_1608Metric; JLCPCB Part # C25803
R11, R12: 4.7k; R_0603_1608Metric; JLCPCB Part # C23162
R13, R14: 3.3k; R_0603_1608Metric; JLCPCB Part # C22978
R15, R17: 470; R_0603_1608Metric; JLCPCB Part # C23179
R16: 10k; R_0603_1608Metric; JLCPCB Part # C25804
U1: ECP5U_12_CABGA256; BGA-256_14.0x14.0mm_Layout16x16_P0.8mm_Ball0.45mm_Pad0.32mm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; JLCPCB Part # C1521614
U9: PCA9306DC1; VSSOP-8_2.3x2mm_P0.5mm; JLCPCB Part # C129510
Y1: ECS-2520MV-xxx-xx; Crystal_SMD_3225-4Pin_3.2x2.5mm; JLCPCB Part # C5189451

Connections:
+3V3: C17.2, C18.1, R13.1, R14.1, U1.K11 (VCCIO3[2]), U1.L11 (VCCIO3[2]), U9.2 (VREF1), U9.8 (EN), Y1.1 (Tri-State), Y1.4 (VDD); also elsewhere on the board
+5V: J5.18 (+5V), R10.1, R11.1, R12.1; also elsewhere on the board
FPDI_CEC: R15.2, U1.T14 (PR41D/-/RDQ44)
FPDI_CLK+: C26.1, U1.T15 (PR38D/-/RDQ44)
FPDI_CLK-: C27.1, U1.R15 (PR38C/+/RDQ44)
FPDI_D0+: C24.1, U1.P16 (PR35A/+/HS/RDQ32)
FPDI_D0-: C25.1, U1.R16 (PR35B/-/VREF1_3/HS/RDQ32)
FPDI_D1+: C22.1, U1.M16 (PR26C/+/PCLKT3_0/RDQ32)
FPDI_D1-: C23.1, U1.M15 (PR26D/-/PCLKC3_0/RDQ32)
FPDI_D2+: C20.1, U1.L16 (PR26A/+/PCLKT3_1/HS/RDQ32)
FPDI_D2-: C21.1, U1.L15 (PR26B/-/PCLKC3_1/HS/RDQ32)
FPDI_HPD: R17.2, U1.N16 (PR32A/+/HS/RDQS32)
FPDI_SCL: R14.2, U9.3 (SCL1); also elsewhere on the board
FPDI_SDA: R13.2, U9.4 (SDA1); also elsewhere on the board
FPDI_UTIL: R16.2, U1.P15 (PR32B/-/HS/RDQSN32)
GCLK: C19.1, U1.K13 (PR29A/+/GR_PCLK3_0/HS/RDQ32), Y1.3 (OUT)
GND: C17.1, C18.2, C19.2, C28.2, J5.1 (D2S), J5.4 (D1S), J5.7 (D0S), J5.10 (CKS), J5.13 (GND), J5.SH, U9.1 (GND), Y1.2 (GND); also elsewhere on the board
GPDI_SCL: J5.15 (SCL), R11.2, U9.6 (SCL2)
GPDI_SDA: J5.16 (SDA), R12.2, U9.5 (SDA2)
unnamed: J5.14 (CEC), R15.1
unnamed: C26.2, J5.11 (CK+)
unnamed: C27.2, J5.12 (CK-)
unnamed: C24.2, J5.8 (D0+)
unnamed: C25.2, J5.9 (D0-)
unnamed: C22.2, J5.5 (D1+)
unnamed: C23.2, J5.6 (D1-)
unnamed: C20.2, J5.2 (D2+)
unnamed: C21.2, J5.3 (D2-)
unnamed: J5.19 (HPD), R17.1
unnamed: J5.17 (UTILITY), R16.1
unnamed: C28.1, R10.2, U9.7 (VREF2)

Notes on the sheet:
Shift 3v3 to 5v

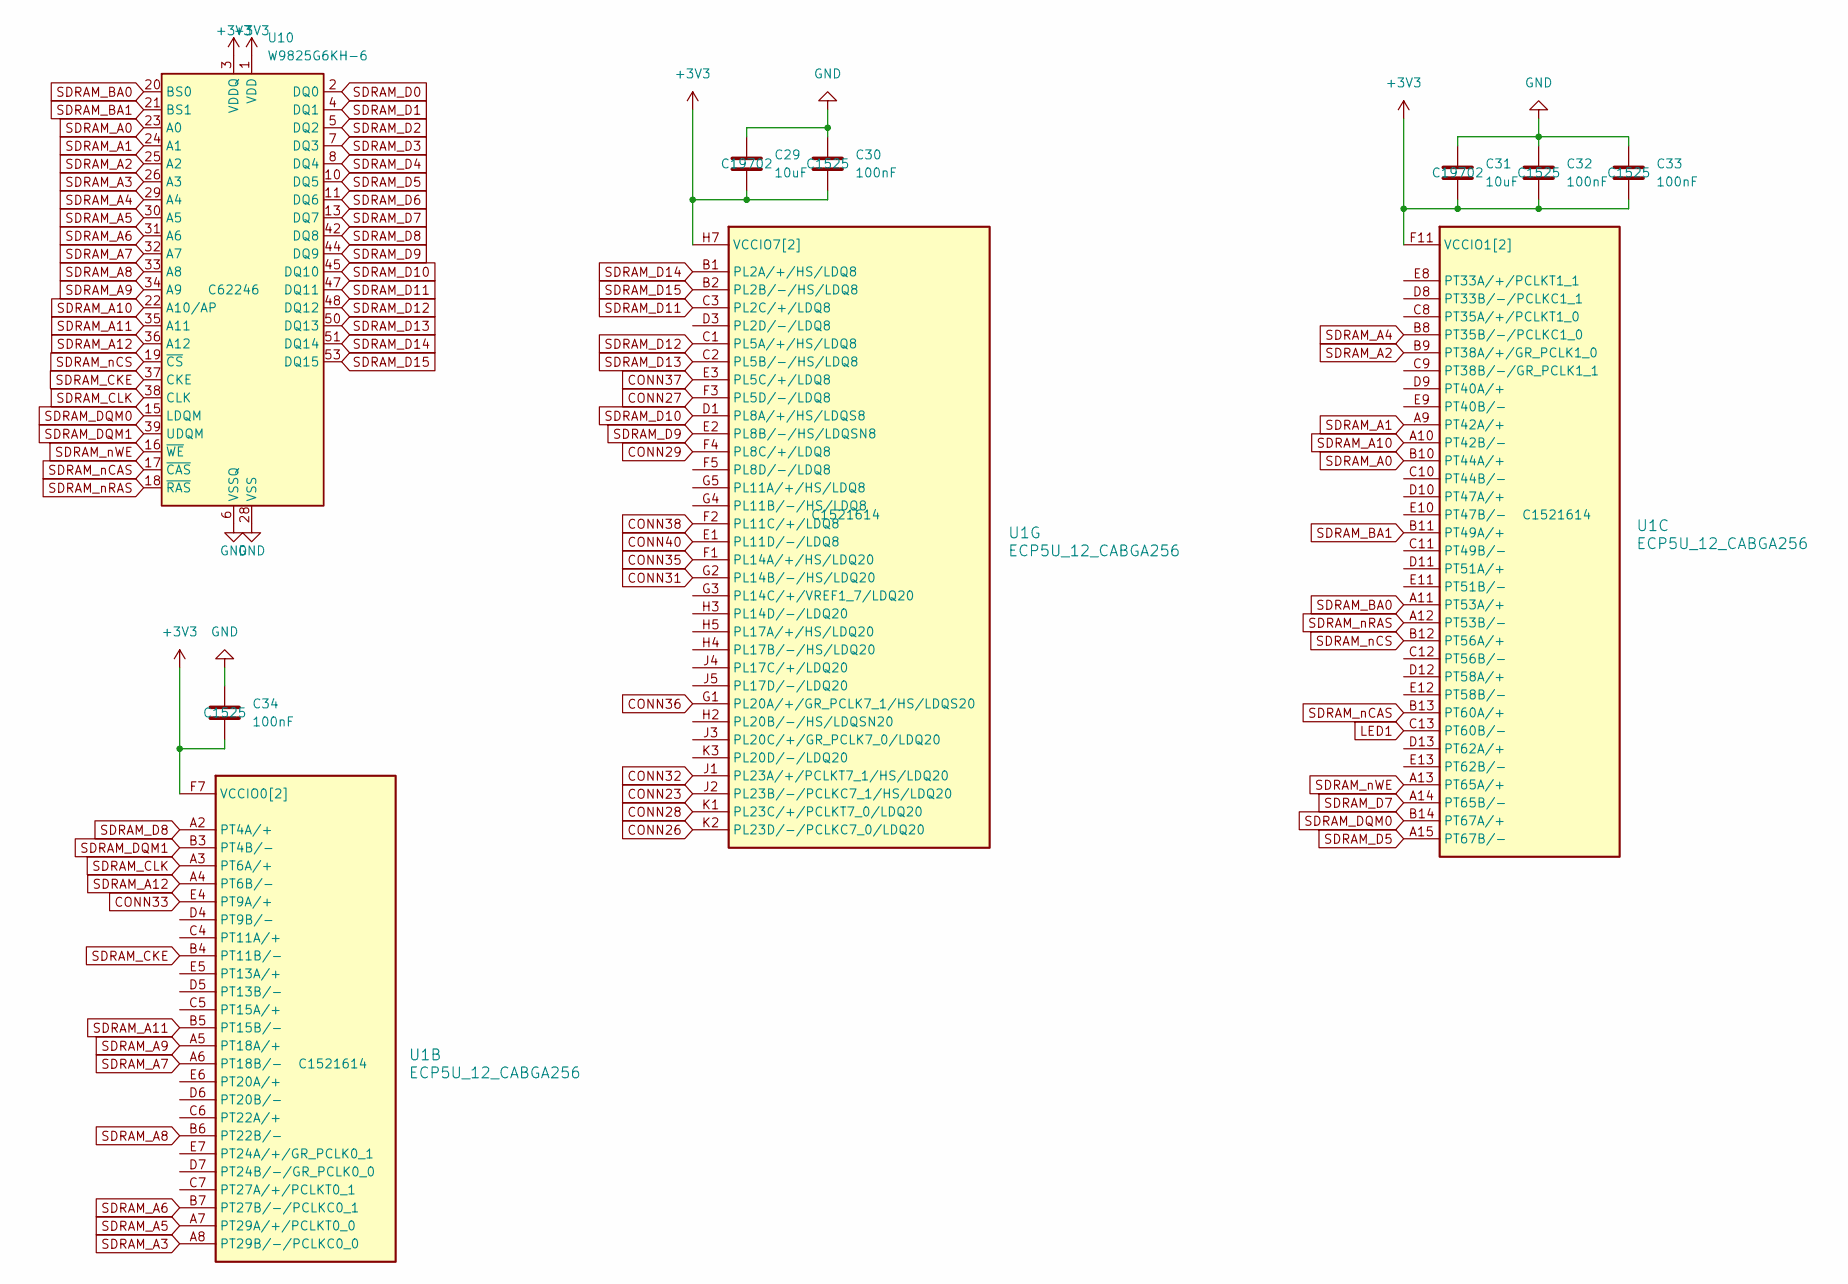
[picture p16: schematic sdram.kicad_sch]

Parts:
C29, C31: 10uF; C_0603_1608Metric; JLCPCB Part # C19702
C30, C32, C33, C34: 100nF; C_0402_1005Metric; JLCPCB Part # C1525
U1: ECP5U_12_CABGA256; BGA-256_14.0x14.0mm_Layout16x16_P0.8mm_Ball0.45mm_Pad0.32mm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; JLCPCB Part # C1521614
U10: W9825G6KH-6; TSOP-II-54_22.2x10.16mm_P0.8mm; JLCPCB Part # C62246

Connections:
+3V3: C29.2, C30.2, C31.2, C32.2, C33.2, C34.2, U1.F6 (VCCIO0[2]), U1.F7 (VCCIO0[2]), U1.F10 (VCCIO1[2]), U1.F11 (VCCIO1[2]), U1.H6 (VCCIO7[2]), U1.H7 (VCCIO7[2]), U10.1 (VDD), U10.3 (VDDQ), U10.9 (VDDQ), U10.14 (VDD), U10.27 (VDD), U10.43 (VDDQ), U10.49 (VDDQ); also elsewhere on the board
CONN23: U1.J2 (PL23B/-/PCLKC7_1/HS/LDQ20); also elsewhere on the board
CONN26: U1.K2 (PL23D/-/PCLKC7_0/LDQ20); also elsewhere on the board
CONN27: U1.F3 (PL5D/-/LDQ8); also elsewhere on the board
CONN28: U1.K1 (PL23C/+/PCLKT7_0/LDQ20); also elsewhere on the board
CONN29: U1.F4 (PL8C/+/LDQ8); also elsewhere on the board
CONN31: U1.G2 (PL14B/-/HS/LDQ20); also elsewhere on the board
CONN32: U1.J1 (PL23A/+/PCLKT7_1/HS/LDQ20); also elsewhere on the board
CONN33: U1.E4 (PT9A/+); also elsewhere on the board
CONN35: U1.F1 (PL14A/+/HS/LDQ20); also elsewhere on the board
CONN36: U1.G1 (PL20A/+/GR_PCLK7_1/HS/LDQS20); also elsewhere on the board
CONN37: U1.E3 (PL5C/+/LDQ8); also elsewhere on the board
CONN38: U1.F2 (PL11C/+/LDQ8); also elsewhere on the board
CONN40: U1.E1 (PL11D/-/LDQ8); also elsewhere on the board
GND: C29.1, C30.1, C31.1, C32.1, C33.1, C34.1, U10.6 (VSSQ), U10.12 (VSSQ), U10.28 (VSS), U10.41 (VSS), U10.46 (VSSQ), U10.52 (VSSQ), U10.54 (VSS); also elsewhere on the board
LED1: U1.C13 (PT60B/-); also elsewhere on the board
SDRAM_A0: U1.B10 (PT44A/+), U10.23 (A0)
SDRAM_A1: U1.A9 (PT42A/+), U10.24 (A1)
SDRAM_A2: U1.B9 (PT38A/+/GR_PCLK1_0), U10.25 (A2)
SDRAM_A3: U1.A8 (PT29B/-/PCLKC0_0), U10.26 (A3)
SDRAM_A4: U1.B8 (PT35B/-/PCLKC1_0), U10.29 (A4)
SDRAM_A5: U1.A7 (PT29A/+/PCLKT0_0), U10.30 (A5)
SDRAM_A6: U1.B7 (PT27B/-/PCLKC0_1), U10.31 (A6)
SDRAM_A7: U1.A6 (PT18B/-), U10.32 (A7)
SDRAM_A8: U1.B6 (PT22B/-), U10.33 (A8)
SDRAM_A9: U1.A5 (PT18A/+), U10.34 (A9)
SDRAM_A10: U1.A10 (PT42B/-), U10.22 (A10/AP)
SDRAM_A11: U1.B5 (PT15B/-), U10.35 (A11)
SDRAM_A12: U1.A4 (PT6B/-), U10.36 (A12)
SDRAM_BA0: U1.A11 (PT53A/+), U10.20 (BS0)
SDRAM_BA1: U1.B11 (PT49A/+), U10.21 (BS1)
SDRAM_CKE: U1.B4 (PT11B/-), U10.37 (CKE)
SDRAM_CLK: U1.A3 (PT6A/+), U10.38 (CLK)
SDRAM_D0: U10.2 (DQ0); also elsewhere on the board
SDRAM_D1: U10.4 (DQ1); also elsewhere on the board
SDRAM_D2: U10.5 (DQ2); also elsewhere on the board
SDRAM_D3: U10.7 (DQ3); also elsewhere on the board
SDRAM_D4: U10.8 (DQ4); also elsewhere on the board
SDRAM_D5: U1.A15 (PT67B/-), U10.10 (DQ5)
SDRAM_D6: U10.11 (DQ6); also elsewhere on the board
SDRAM_D7: U1.A14 (PT65B/-), U10.13 (DQ7)
SDRAM_D8: U1.A2 (PT4A/+), U10.42 (DQ8)
SDRAM_D9: U1.E2 (PL8B/-/HS/LDQSN8), U10.44 (DQ9)
SDRAM_D10: U1.D1 (PL8A/+/HS/LDQS8), U10.45 (DQ10)
SDRAM_D11: U1.C3 (PL2C/+/LDQ8), U10.47 (DQ11)
SDRAM_D12: U1.C1 (PL5A/+/HS/LDQ8), U10.48 (DQ12)
SDRAM_D13: U1.C2 (PL5B/-/HS/LDQ8), U10.50 (DQ13)
SDRAM_D14: U1.B1 (PL2A/+/HS/LDQ8), U10.51 (DQ14)
SDRAM_D15: U1.B2 (PL2B/-/HS/LDQ8), U10.53 (DQ15)
SDRAM_DQM0: U1.B14 (PT67A/+), U10.15 (LDQM)
SDRAM_DQM1: U1.B3 (PT4B/-), U10.39 (UDQM)
SDRAM_nCAS: U1.B13 (PT60A/+), U10.17 (~CAS)
SDRAM_nCS: U1.B12 (PT56A/+), U10.19 (~CS)
SDRAM_nRAS: U1.A12 (PT53B/-), U10.18 (~RAS)
SDRAM_nWE: U1.A13 (PT65A/+), U10.16 (~WE)

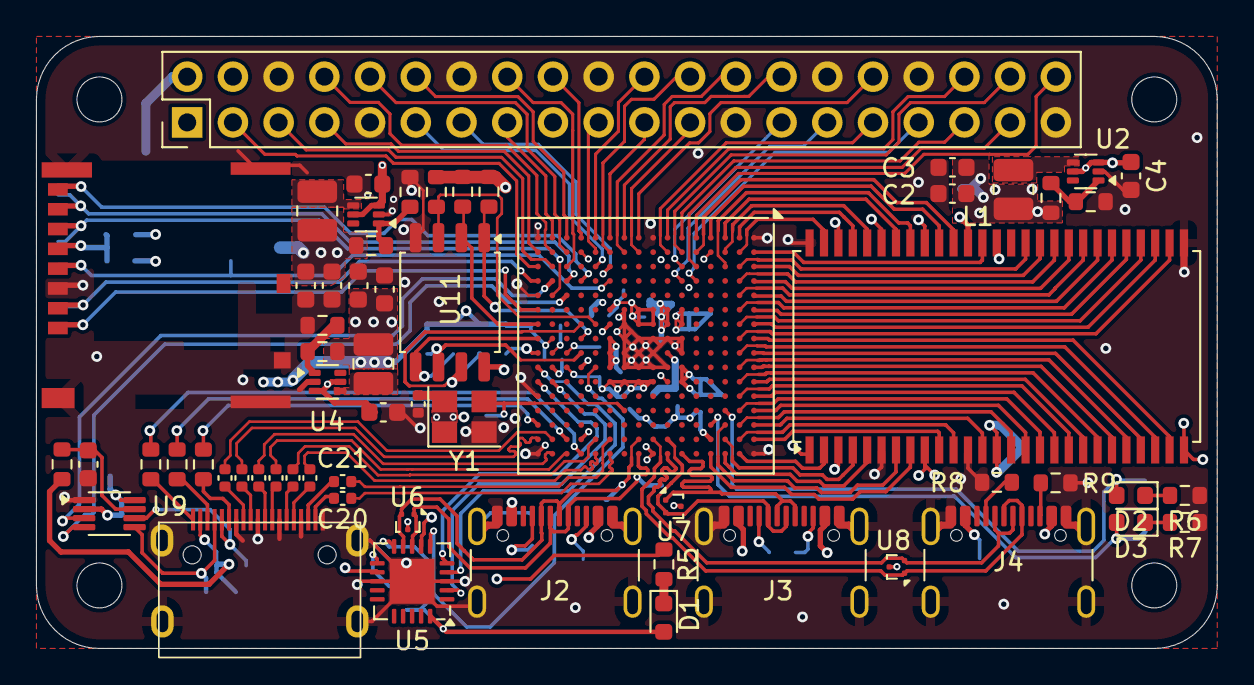
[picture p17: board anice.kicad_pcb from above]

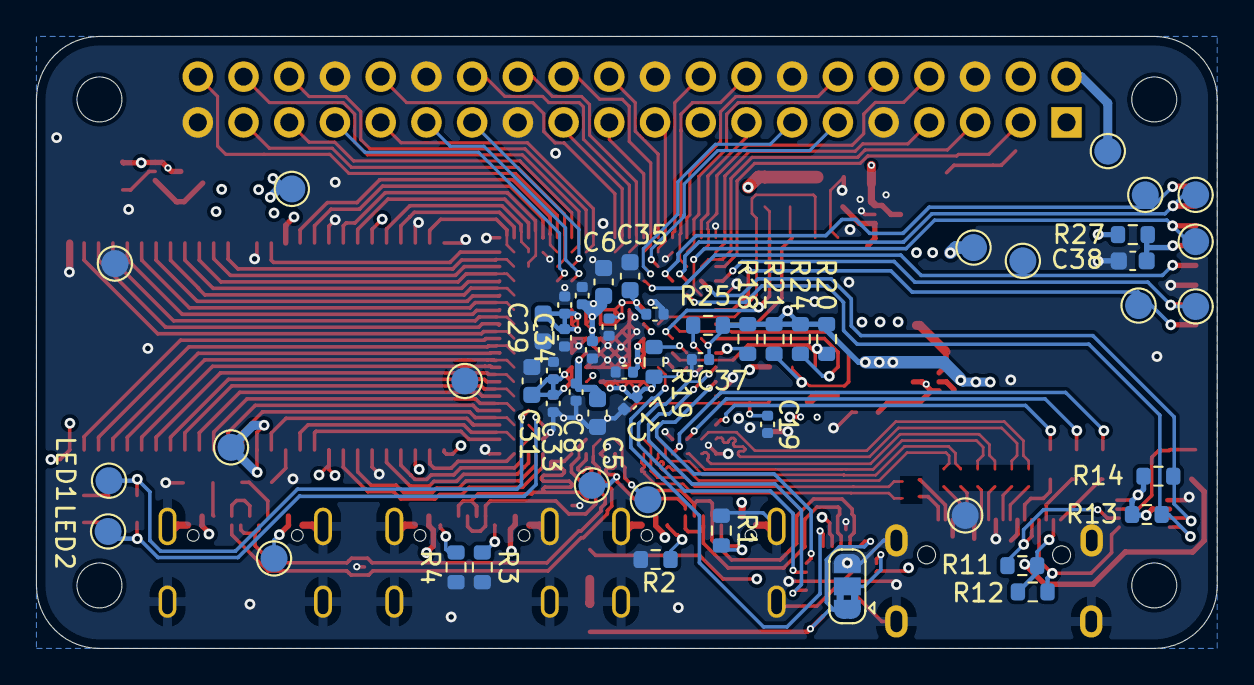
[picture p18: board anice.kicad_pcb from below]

Board: 4 copper layers, 65.6 x 34.0 mm, 118 parts (53 on the bottom side), 146 nets.

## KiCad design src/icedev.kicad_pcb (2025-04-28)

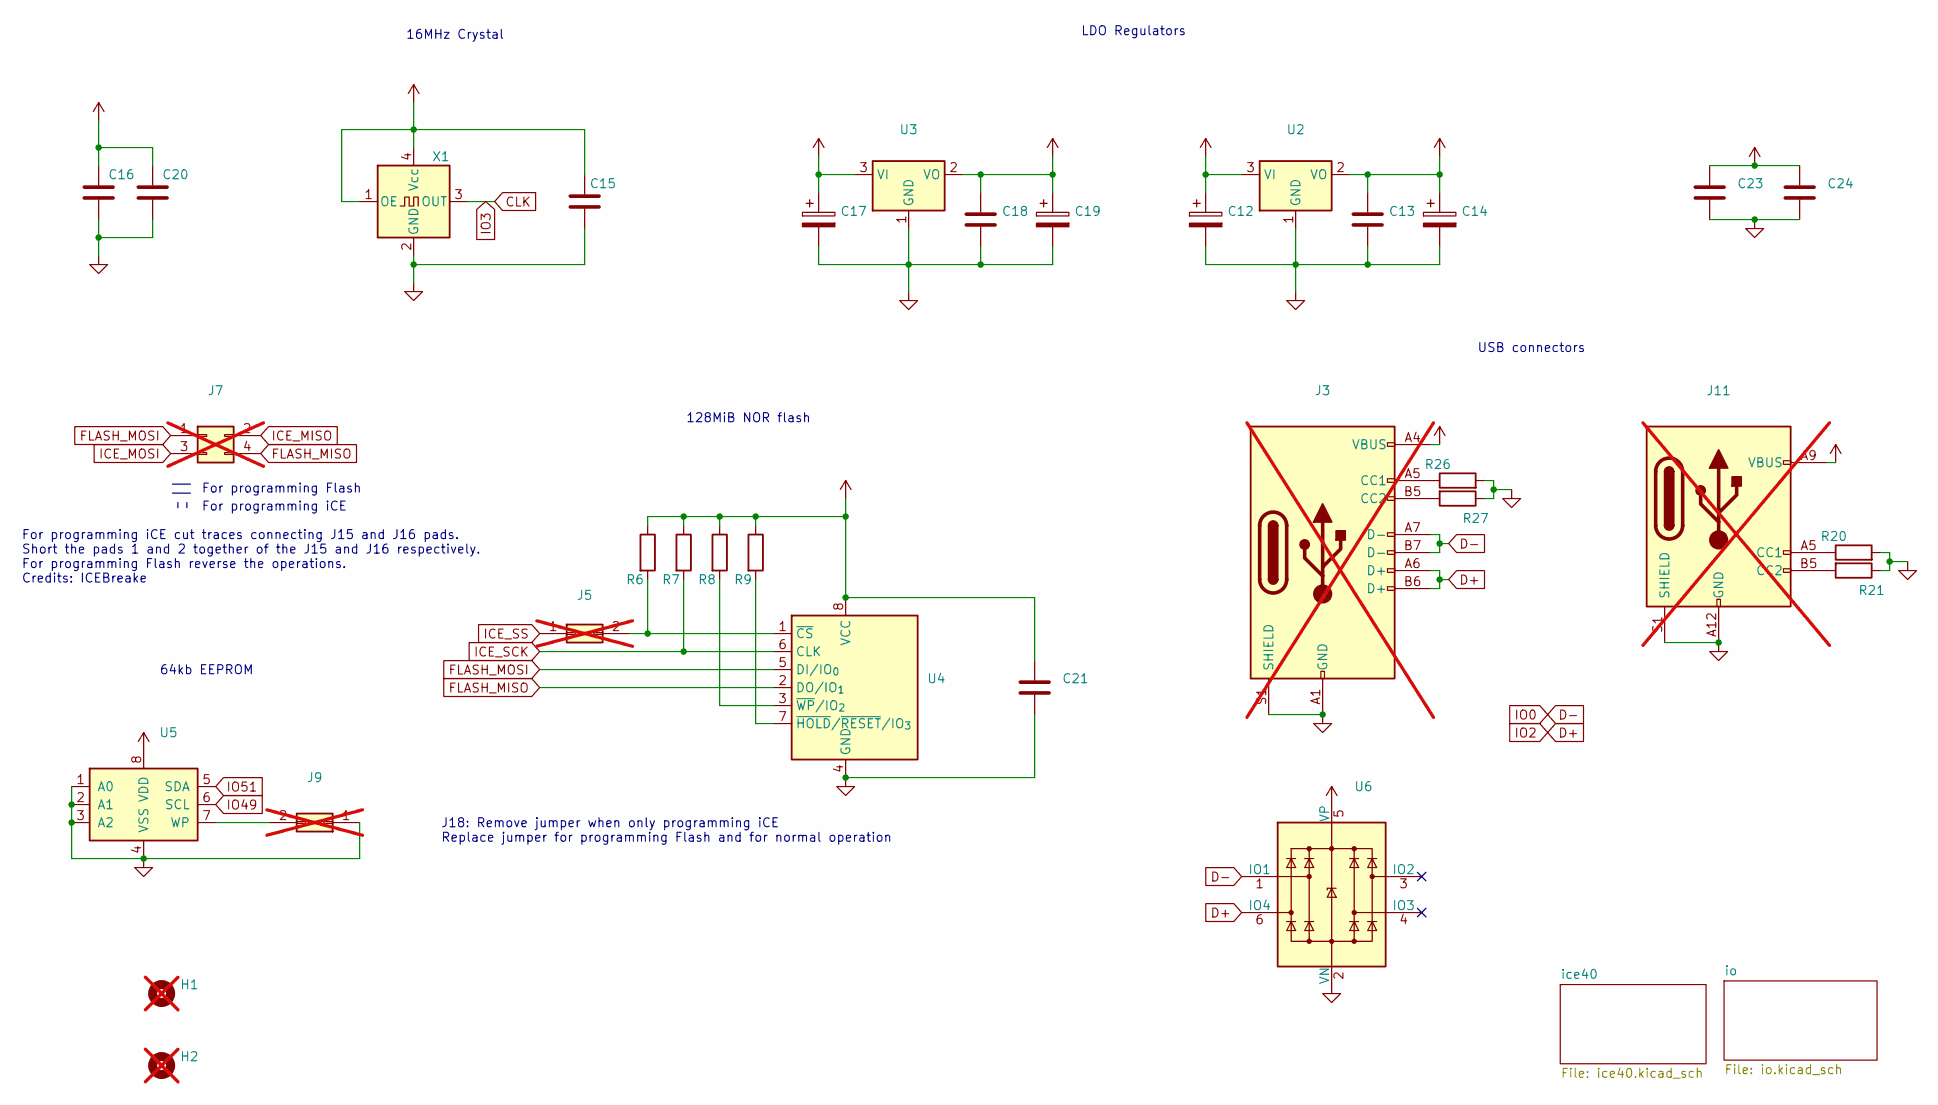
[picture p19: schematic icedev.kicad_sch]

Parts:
C12, C14, C17, C19: 10u; C_0402_1005Metric; JLCPCB Part # C15525
C13, C15, C16, C18, C21, C23, C24: 0.1u; C_0402_1005Metric; JLCPCB Part # C1525
C20: 10n; C_0402_1005Metric; JLCPCB Part # C15195
H1, H2: MountingHole; MountingHole_2.2mm_M2; not fitted
J3: USB_C_Receptacle_USB2.0_14P; USB_C_Receptacle_GCT_USB4105-xx-A_16P_TopMnt_Horizontal; not fitted
J5, J9: Conn_02x01; PinHeader_2x01_P2.54mm_Vertical; not fitted
J7: Conn_02x02_Odd_Even; PinSocket_2x02_P2.54mm_Vertical; not fitted
J11: USB_C_Receptacle_PowerOnly_6P; USB_C_Receptacle_GCT_USB4135-GF-A_6P_TopMnt_Horizontal; not fitted
R6, R7, R8, R9: 10K; R_0805_2012Metric; JLCPCB Part # C17414
R20, R21: 5.1K; R_0402_1005Metric; JLCPCB Part # C25905
R26, R27: 5.1K; R_0805_2012Metric; JLCPCB Part # C27834
U2: AMS1117-1.2; SOT-223-3_TabPin2; JLCPCB Part # C14529
U3: AMS1117-3.3; SOT-223-3_TabPin2; JLCPCB Part # C6186
U4: W25Q128JVS; SOIC-8_5.3x5.3mm_P1.27mm; JLCPCB Part # C97521
U5: FM24C64B; SOIC-8_3.9x4.9mm_P1.27mm; JLCPCB Part # C79988
U6: SRV05-4; SOT-23-6-routable; JLCPCB Part # C85364
X1: MPUOSC; Oscillator_SMD_Abracon_ASE-4Pin_3.2x2.5mm; JLCPCB Part # C13738

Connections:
+1V2: C13.1, C14.1, C16.1, C20.1, U2.2 (VO); also elsewhere on the board
+3V3: C12.1, C15.1, C18.1, C19.1, C21.1, R6.1, R7.1, R8.1, R9.1, U2.3 (VI), U3.2 (VO), U4.8 (VCC), U5.8 (VDD), X1.1 (OE), X1.4 (Vcc); also elsewhere on the board
+5V: C17.1, C23.1, C24.1, J3.A4 (VBUS), J3.A9 (VBUS), J3.B4 (VBUS), J3.B9 (VBUS), J11.A9 (VBUS), J11.B9 (VBUS), U3.3 (VI), U6.5 (VP); also elsewhere on the board
CLK: X1.3 (OUT); also elsewhere on the board
D+: J3.A6 (D+), J3.B6 (D+), U6.6 (IO4); also elsewhere on the board
D-: J3.A7 (D-), J3.B7 (D-), U6.1 (IO1); also elsewhere on the board
FLASH_MISO: J7.4, U4.2 (DO/IO_{1}); also elsewhere on the board
FLASH_MOSI: J7.1, U4.5 (DI/IO_{0}); also elsewhere on the board
GND: C12.2, C13.2, C14.2, C15.2, C16.2, C17.2, C18.2, C19.2, C20.2, C21.2, C23.2, C24.2, J3.A1 (GND), J3.A12 (GND), J3.B1 (GND), J3.B12 (GND), J3.S1 (SHIELD), J9.1, J11.A12 (GND), J11.B12 (GND), J11.S1 (SHIELD), R20.2, R21.1, R26.2, R27.1, U2.1 (GND), U3.1 (GND), U4.4 (GND), U5.1 (A0), U5.2 (A1), U5.3 (A2), U5.4 (VSS), U6.2 (VN), X1.2 (GND); also elsewhere on the board
ICE_MISO: J7.2; also elsewhere on the board
ICE_MOSI: J7.3; also elsewhere on the board
ICE_SCK: R7.2, U4.6 (CLK); also elsewhere on the board
ICE_SS: J5.1; also elsewhere on the board
IO49: U5.6 (SCL); also elsewhere on the board
IO51: U5.5 (SDA); also elsewhere on the board
unnamed: J3.A5 (CC1), R26.1
unnamed: J3.B5 (CC2), R27.2
unnamed: J5.2, R6.2, U4.1 (~CS)
unnamed: J9.2, U5.7 (WP)
unnamed: J11.A5 (CC1), R20.1
unnamed: J11.B5 (CC2), R21.2
unnamed: R9.2, U4.7 (~HOLD/~RESET/IO_{3})
unnamed: R8.2, U4.3 (~WP/IO_{2})

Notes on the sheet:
For programming Flash
J18: Remove jumper when only programming iCE Replace jumper for programming Flash and for normal operation
64kb EEPROM
16MHz Crystal
USB connectors
For programming iCE cut traces connecting J15 and J16 pads. Short the pads 1 and 2 together of the J15 and J16 respectively. For programming Flash reverse the operations. Credits: ICEBreake
128MiB NOR flash
LDO Regulators
For programming iCE

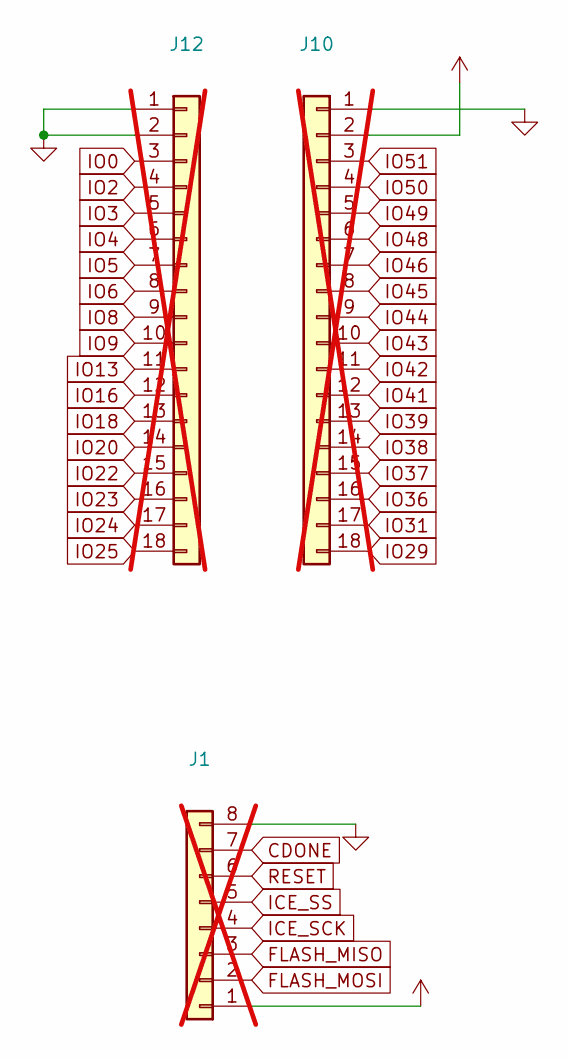
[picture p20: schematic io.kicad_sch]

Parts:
J1: Conn_01x08; PinSocket_1x08_P2.54mm_Vertical; not fitted
J10, J12: Conn_01x18; PinSocket_1x18_P2.54mm_Vertical; not fitted

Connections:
+5V: J1.1, J10.2; also elsewhere on the board
CDONE: J1.7; also elsewhere on the board
CLK: J12.5; also elsewhere on the board
D+: J12.4; also elsewhere on the board
D-: J12.3; also elsewhere on the board
FLASH_MISO: J1.3; also elsewhere on the board
FLASH_MOSI: J1.2; also elsewhere on the board
GND: J1.8, J10.1, J12.1, J12.2; also elsewhere on the board
ICE_SCK: J1.4; also elsewhere on the board
ICE_SS: J1.5; also elsewhere on the board
IO4: J12.6; also elsewhere on the board
IO5: J12.7; also elsewhere on the board
IO6: J12.8; also elsewhere on the board
IO8: J12.9; also elsewhere on the board
IO9: J12.10; also elsewhere on the board
IO13: J12.11; also elsewhere on the board
IO16: J12.12; also elsewhere on the board
IO18: J12.13; also elsewhere on the board
IO20: J12.14; also elsewhere on the board
IO22: J12.15; also elsewhere on the board
IO23: J12.16; also elsewhere on the board
IO24: J12.17; also elsewhere on the board
IO25: J12.18; also elsewhere on the board
IO29: J10.18; also elsewhere on the board
IO31: J10.17; also elsewhere on the board
IO36: J10.16; also elsewhere on the board
IO37: J10.15; also elsewhere on the board
IO38: J10.14; also elsewhere on the board
IO39: J10.13; also elsewhere on the board
IO41: J10.12; also elsewhere on the board
IO42: J10.11; also elsewhere on the board
IO43: J10.10; also elsewhere on the board
IO44: J10.9; also elsewhere on the board
IO45: J10.8; also elsewhere on the board
IO46: J10.7; also elsewhere on the board
IO48: J10.6; also elsewhere on the board
IO49: J10.5; also elsewhere on the board
IO50: J10.4; also elsewhere on the board
IO51: J10.3; also elsewhere on the board
RESET: J1.6; also elsewhere on the board

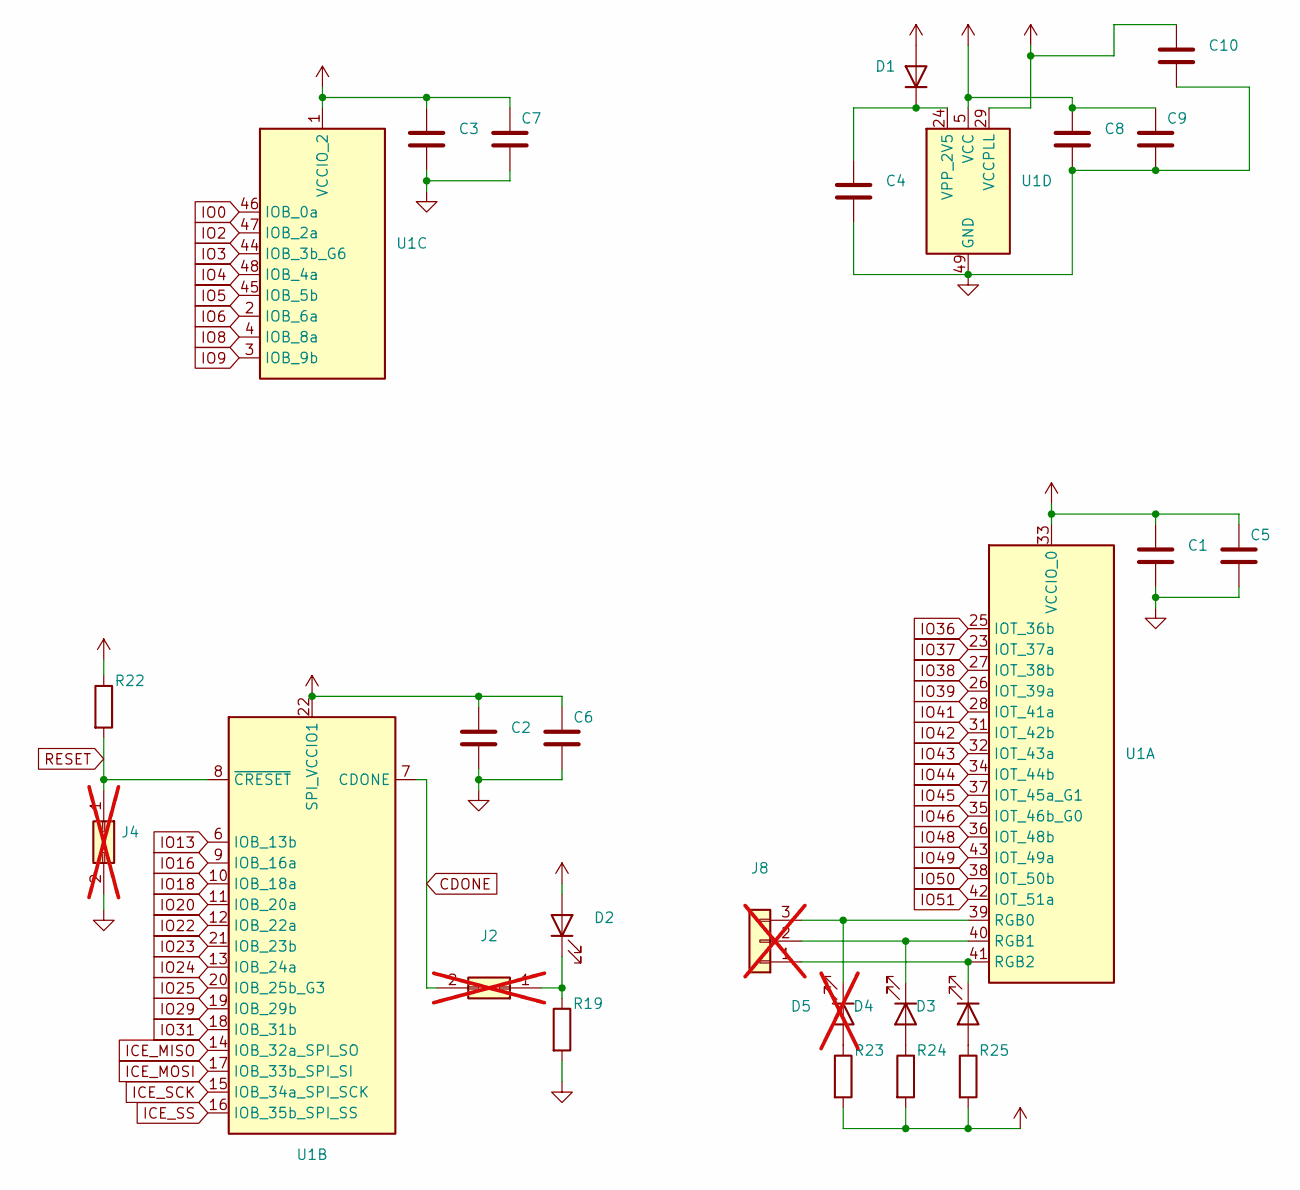
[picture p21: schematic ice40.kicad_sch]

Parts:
C1, C2, C3, C4, C8, C10: 0.1u; C_0402_1005Metric; JLCPCB Part # C1525
C5, C6, C7, C9: 10n; C_0402_1005Metric; JLCPCB Part # C15195
D1: Schottky Diode; D_SOD-123; JLCPCB Part # C8598
D2, D4: G; LED_0805_2012Metric; JLCPCB Part # C2297
D3: R; LED_0603_1608Metric; JLCPCB Part # C2286
D5: B; LED_0201_0603Metric_Pad0.64x0.40mm_HandSolder; not fitted
J2, J4: Conn_02x01; PinHeader_2x01_P2.54mm_Vertical; not fitted
J8: Conn_01x03; PinHeader_1x03_P2.54mm_Vertical; not fitted
R19, R22, R23, R24, R25: 1K; R_0805_2012Metric; JLCPCB Part # C17513
U1: ICE40UP5K-SG48ITR; QFN-48-1EP_7x7mm_P0.5mm_EP5.6x5.6mm; JLCPCB Part # C2678152

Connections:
+1V2: C8.1, C9.1, C10.1, U1.5 (VCC), U1.29 (VCCPLL), U1.30 (VCC); also elsewhere on the board
+3V3: C1.1, C2.1, C3.1, C5.1, C6.1, C7.1, D1.2 (A), D2.2 (A), R22.1, R23.2, R24.2, R25.2, U1.1 (VCCIO_2), U1.22 (SPI_VCCIO1), U1.33 (VCCIO_0); also elsewhere on the board
CDONE: J2.2, U1.7 (CDONE); also elsewhere on the board
CLK: U1.44 (IOB_3b_G6); also elsewhere on the board
D+: U1.47 (IOB_2a); also elsewhere on the board
D-: U1.46 (IOB_0a); also elsewhere on the board
GND: C1.2, C2.2, C3.2, C4.2, C5.2, C6.2, C7.2, C8.2, C9.2, C10.2, J4.2, R19.2, U1.49 (GND); also elsewhere on the board
ICE_MISO: U1.14 (IOB_32a_SPI_SO); also elsewhere on the board
ICE_MOSI: U1.17 (IOB_33b_SPI_SI); also elsewhere on the board
ICE_SCK: U1.15 (IOB_34a_SPI_SCK); also elsewhere on the board
ICE_SS: U1.16 (IOB_35b_SPI_SS); also elsewhere on the board
IO4: U1.48 (IOB_4a); also elsewhere on the board
IO5: U1.45 (IOB_5b); also elsewhere on the board
IO6: U1.2 (IOB_6a); also elsewhere on the board
IO8: U1.4 (IOB_8a); also elsewhere on the board
IO9: U1.3 (IOB_9b); also elsewhere on the board
IO13: U1.6 (IOB_13b); also elsewhere on the board
IO16: U1.9 (IOB_16a); also elsewhere on the board
IO18: U1.10 (IOB_18a); also elsewhere on the board
IO20: U1.11 (IOB_20a); also elsewhere on the board
IO22: U1.12 (IOB_22a); also elsewhere on the board
IO23: U1.21 (IOB_23b); also elsewhere on the board
IO24: U1.13 (IOB_24a); also elsewhere on the board
IO25: U1.20 (IOB_25b_G3); also elsewhere on the board
IO29: U1.19 (IOB_29b); also elsewhere on the board
IO31: U1.18 (IOB_31b); also elsewhere on the board
IO36: U1.25 (IOT_36b); also elsewhere on the board
IO37: U1.23 (IOT_37a); also elsewhere on the board
IO38: U1.27 (IOT_38b); also elsewhere on the board
IO39: U1.26 (IOT_39a); also elsewhere on the board
IO41: U1.28 (IOT_41a); also elsewhere on the board
IO42: U1.31 (IOT_42b); also elsewhere on the board
IO43: U1.32 (IOT_43a); also elsewhere on the board
IO44: U1.34 (IOT_44b); also elsewhere on the board
IO45: U1.37 (IOT_45a_G1); also elsewhere on the board
IO46: U1.35 (IOT_46b_G0); also elsewhere on the board
IO48: U1.36 (IOT_48b); also elsewhere on the board
IO49: U1.43 (IOT_49a); also elsewhere on the board
IO50: U1.38 (IOT_50b); also elsewhere on the board
IO51: U1.42 (IOT_51a); also elsewhere on the board
unnamed: C4.1, D1.1 (K), U1.24 (VPP_2V5)
unnamed: D2.1 (K), J2.1, R19.1
unnamed: D3.2 (A), R25.1
unnamed: D3.1 (K), J8.1, U1.41 (RGB2)
unnamed: D4.2 (A), R24.1
unnamed: D4.1 (K), J8.2, U1.40 (RGB1)
unnamed: D5.2 (A), R23.1
unnamed: D5.1 (K), J8.3, U1.39 (RGB0)
RESET: J4.1, R22.2, U1.8 (~CRESET); also elsewhere on the board

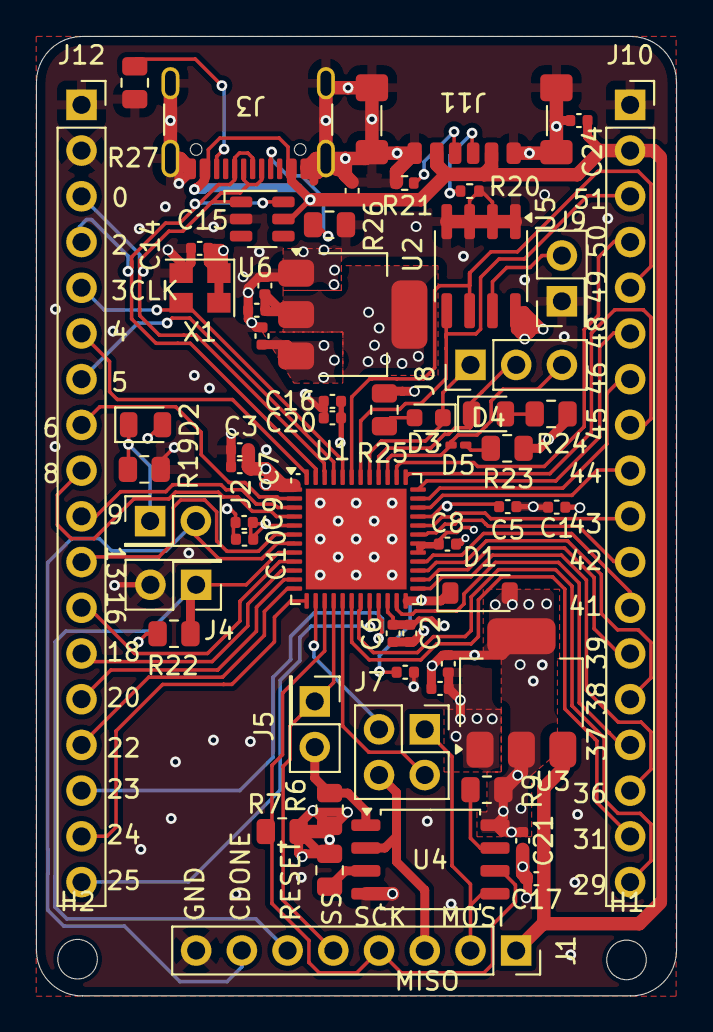
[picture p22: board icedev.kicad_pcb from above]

Board: 4 copper layers, 35.6 x 53.3 mm, 60 parts (0 on the bottom side), 60 nets.

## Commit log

2025-04-22 started routing
    [anice-halfrouted.kicad_pcb, anice.kicad_pcb, anice.kicad_sch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]
2025-04-22 Add a gitignore
    [anice.kicad_pcb]
2025-04-23 Routed HDMI, usb, rotated chip and more
    [5033981892.stp, anice.kicad_pcb, anice.kicad_sch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]
2025-04-25 Rev 1
    [anice.kicad_pcb, anice.kicad_sch, flash.kicad_sch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]
2025-04-25 No DRC Errors
    [anice.kicad_pcb, anice.kicad_sch, flash.kicad_sch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]
2025-04-25 Structure project
    [5033981892.stp, anice-halfrouted.kicad_pcb, anice.kicad_pcb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]
2025-04-25 Clean up repo
    [anice.kicad_pcb]
2025-04-26 Rev 2
    [anice.kicad_pcb, anice.kicad_sch, bom.csv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]
2025-04-26 Tidy project
    [anice.kicad_pcb, anice.kicad_sch, flash.kicad_sch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]
2025-04-26 Add test points
    [anice.kicad_pcb, anice.kicad_sch, flash.kicad_sch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]
2025-04-28 Add annotations
    [anice.kicad_pcb, icedev.kicad_pcb]
2025-04-28 Fix date
    [anice.kicad_pcb]
